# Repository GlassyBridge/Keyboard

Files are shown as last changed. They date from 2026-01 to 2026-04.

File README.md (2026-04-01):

<h1 align="center"> MK-1000 </h1>
<h4 align="center">A Modular-Wireless Keyboard </h4>
<div align="center">
  
</div>
<p align="center">A fully custom modular keyboard that has both wireless and wired capabilities, uses MX hotswap switches (with per key RGB lighting) and magnetic pogo pin connectors with I2C protocol.</p>
<h2></h2>
<h2> Features </h2>

- Works over USB-C (wired) or Bluetooth (wireless)
- Integrated magnetic pogo pins for stable I2C connection and adding external modules (numberpads, macropads or OLED modules)
- Integrated charging circuit for portability and wireless operation
- Uses MX hotswap sockets for key switch connections
- Features SK6812MINI-E back mounted LEDs for customizable per key RGB lighting
- Includes a dedicated SWD interface for debugging and development
- A dedicated slide switch to manage battery life

<h2> Why this project? </h2>

This project was made as an attempt to tackle more complex hardware from my previous projects. I spent a lot of time designing and reiterating it and its purpose is simple. I made it to function as a plug and play device that has modular capabilities.

I also wanted a cool looking keyboard so I added features I liked into this one big project.

<h2>Design</h2>
<h3>Schematic</h3>
Main_Board_Schematic
Keypad_Module_Schematic
<h4 align="center">Main board & Keypad</h4>
<h3>PCB</h3>
Back PCB
<h4 align="center">PCB back</h4>
Front PCB
<h4 align="center">PCB front</h4>
PCB
<h4 align="center">PCB</h4>
No-Components 3D View front
No-Components 3D View back
<h4 align="center">PCB 3D model</h4>
3D view front
3D view back
<h4 align="center">PCB 3D model with components</h4>
How to connect the batteries
<h4 align="center">Wiring Diagram</h4>

<h2>Firmware</h2>

Available in the `Firmware` folder. (Basic version for now. I'll update it once I built the keyboard)
<h2>Bill of Materials</h2>

| Name | Reference | Qty | moq | Price ($) | Shipping | Link |
| --- | --- | :---: | --- | --- | --- | :---: |
| OLED Screens (128X32) | Brd11 | 1 | 1 | 2.42 | Aliexpress | [Aliexpress](https://www.aliexpress.us/item/3256806165075447.html) |
| ------------ (128X64) | Brd12 | 1 | 1 | 4.18 | Aliexpress | [Aliexpress](https://www.aliexpress.us/item/3256810159598938.html) |
| 1X6 Magnetic Pogo Pins | Conn1-Conn8 | 8(4 pairs) | 5p  | 25.25 | Aliexpress | [Aliexpress](https://www.aliexpress.us/item/3256805098127227.html) |
| Capacitors (10uF) | C1-C4 | 4 | 20  | 0.43 | LCSC | [C15850](https://www.lcsc.com/product-detail/C15850.html) |
| ---------- (4.7uF) | C5,C6 | 2 | 20  | 0.29 | LCSC | [C1779](https://www.lcsc.com/product-detail/C1779.html) |
| ---------- (22uF) | C7,C8 | 2 | 20  | 1.12 | LCSC | [C12891](https://www.lcsc.com/product-detail/C12891.html) |
| Diodes | D1-D99 | 99 | 100 | 0.93 | LCSC | [C2099](https://www.lcsc.com/product-detail/C2099.html) |
| ---------- (SS34) | SS34 | 1 | 20  | 0.56 | LCSC | [C908680](https://www.lcsc.com/product-detail/C908680.html) |
| ESDA5V3L | ESD1,ESD2 | 2 | 10  | 0.39 | LCSC | [C587142](https://www.lcsc.com/product-detail/C587142.html) |
| USB Connector | J1 | 1 | 5 | 0.84 | LCSC | [C165948](https://www.lcsc.com/product-detail/C165948.html) |
| 2x3 1mm PinHeader | J2 | 1 | 20  | 0.65 | LCSC | [C6837603](https://www.lcsc.com/product-detail/C6837603.html) |
| Inductors  (10uH) | L1 | 1 | 10  | 0.47 | LCSC | [C88173](https://www.lcsc.com/product-detail/C88173.html) |
| ---------- (22uH) | L2 | 1 | 5 | 0.83 | LCSC | [C27442](https://www.lcsc.com/product-detail/C27442.html) |
| SK6812MINI-E (LEDs) | LED1-LED99  | 99 | 100 | 7.45 | LCSC | [C5149201](https://www.lcsc.com/product-detail/C5149201.html) |
| P_Mosfets | Q1-Q3 | 3 | 10  | 0.65 | LCSC | [C10487](https://www.lcsc.com/product-detail/C10487.html) |
| Resistors  (110K) | R1 | 2 | 100 | 0.19 | LCSC | [C2907221](https://www.lcsc.com/product-detail/C2907221.html) |
| ---------- (5K1) | R2,R4 | 2 | 100 | 0.24 | LCSC | [C27834](https://www.lcsc.com/product-detail/C27834.html) |
| ---------- (100K) | R3,R5,R6 | 2 | 100 | 0.22 | LCSC | [C2933502](https://www.lcsc.com/product-detail/C2933502.html) |
| ---------- (4K7) | R7,R12,R18  | 4 | 100 | 0.19 | LCSC | [C17673](https://www.lcsc.com/product-detail/C17673.html) |
| ---------- (27R) | R8,R11 | 2 | 100 | 0.22 | LCSC | [C17594](https://www.lcsc.com/product-detail/C17594.html) |
| ---------- (806K) | R9,R16,R21  | 3 | 100 | 0.22 | LCSC | [C2933502](https://www.lcsc.com/product-detail/C2933502.html) |
| ---------- (2M) | R10,R17,R22 | 3 | 100 | 0.30 | LCSC | [C26112](https://www.lcsc.com/product-detail/C26112.html) |
| ---------- (15K) | R13 | 1 | 100 | 0.21 | LCSC | [C2930170](https://www.lcsc.com/product-detail/C2930170.html) |
| ---------- (10K) | R14,R19 | 2 | 100 | 0.25 | LCSC | [C17414](https://www.lcsc.com/product-detail/C17414.html) |
| ---------- (2K) | R15 | 1 | 100 | 0.25 | LCSC | [C17604](https://www.lcsc.com/product-detail/C17604.html) |
| Rotary Encoder | RE1 | 1 | 1 | 1.87 | LCSC | [C470742](https://www.lcsc.com/product-detail/C470742.html) |
| Slide switch (1825232-1) | SPDT1 | 1 | 1 | 0.93 | LCSC | [C5167252](https://www.lcsc.com/product-detail/C5167252.html) |
| MT3608 | U1 | 1 | 10  | 0.79 | LCSC | [C84817](https://www.lcsc.com/product-detail/C84817.html) |
| USB6B1 | U2 | 1 | 1 | 0.47 | LCSC | [C283483](https://www.lcsc.com/product-detail/C283483.html) |
| MDBT50Q-1MV2 (MCU) | U3 | 1 | 1 | 10.10 | SEED | [Seed Studio](https://www.seeedstudio.com/MDBT50Q-1M-nRF52840-Based-BLE-Module-p-3147.html) |
| MCP73831T-2ACI/OT | U4 | 1 | 1 | 0.74 | LCSC | [C424093](https://www.lcsc.com/product-detail/C424093.html) |
| XIAO-nRF52840-SMD (MCU)  | U5 | 1 | 1 | 9.90 | 3.75 | [Seed Studio](https://www.seeedstudio.com/Seeed-XIAO-BLE-nRF52840-p-5201.html) |
| MCP23017 | U6 | 1 | 1 | 2.03 | LCSC | [C639770](https://www.lcsc.com/product-detail/C639770.html) |
| 74LV1T08GV | U7,U8 | 2 | 1 | 2.12 | LCSC | [C547934](https://www.lcsc.com/product-detail/C547934.html) |
| Keys ----- (Sockets) | SW1-SW99 | 99 | 110 | 8.18 | Aliexpress | [Aliexpress](https://www.aliexpress.us/item/3256809001207500.html) |
| ---------- (Switches) | - | 99 | 105 | 21.85 (T) | Aliexpress | [Aliexpress](https://www.aliexpress.us/item/3256807647145642.html) |
| ---------- (Key Caps) | - | 99 | - | 7.48 (T)  | Aliexpress | [Aliexpress](https://www.aliexpress.us/item/3256808975886837.html) |
| ---------- (Stabilizers) | - | 5 | - | 5.78 (T)  | Aliexpress | [Aliexpress](https://www.aliexpress.us/item/3256801499984864.html) |
| lithium batteries | - | 2 | - | 18.16 (T) | Aliexpress | [Aliexpress](https://www.aliexpress.us/item/3256811743915654.html) |

> *T for total price

| Supplier | cost  | Shipping | Total cost |
| --- | ----- | --- | --- |
| LCSC | 24.65 | 13.08 | 37.73 |
| Aliexpress | 93.30 | 2.69 | 96.44 |
| SEED | 20 | 8.55 | 28.55 |
| JLCPCB | 29.90 | 20.14 | 50.04 |
| Total | - | - | 212.76 |

<h2>Keyboard Case</h2>

A very basic case is provided in the `CAD` folder.



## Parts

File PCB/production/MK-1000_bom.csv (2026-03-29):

Designator | Footprint | Quantity | Value | LCSC Part #
BRD1 | OLED-TH_L38.0-W12.0_HS91L02W2C01 | 1 | SH1106
BRD2 | 128x64OLED | 1 | SH1106
C1, C2, C3, C4 | 0805 | 4 | 10uF | C15850
C5, C6 | 0805 | 2 | 4.7uF | C1779
C7, C8 | 1206 | 2 | 22uF
CONN1, CONN3, CONN5, CONN7 | Pogopin_Conn_1x4_Female | 4 | Conn_01x04_Pin
CONN2, CONN4, CONN6, CONN8 | Pogopin_Conn_1x4_Male | 4 | Conn_01x04_Pin
D1, D10, D11, D12, D13, D14, D15, D16, D17, D18, D19, D2, D20, D21, D22, D23, D24, D25, D26, D27, D28, D29, D3, D30, D31, D32, D33, D34, D35, D36, D37, D38, D39, D4, D40, D41, D42, D43, D44, D45, D46, D47, D48, D49, D5, D50, D51, D52, D53, D54, D55, D56, D57, D58, D59, D6, D60, D61, D62, D63, D64, D65, D66, D67, D68, D69, D7, D70, D71, D72, D73, D74, D75, D76, D77, D78, D79, D8, D80, D81, D82, D83, D84, D85, D86, D87, D88, D89, D9, D90, D91, D92, D93, D94, D95, D96, D97, D98, D99 | D_SOD-123 | 99 | D | C2099
ESD1, ESD2 | SOT-23-3 | 2 | ESDA5V3L | C587142
J1 | USB_C_Receptacle_HRO_TYPE-C-31-M-12 | 1 | USB_C_Receptacle_USB2.0_14P | C165948
J2 | PinHeader_2x03_P1.00mm_Vertical | 1 | Conn_02x03_Odd_Even | C6837603
L1 | 0805 | 1 | 10uH
L2 | IND-SMD_L7.1-W6.6 | 1 | 22uH
LED1, LED10, LED11, LED12, LED13, LED14, LED15, LED16, LED17, LED18, LED19, LED2, LED20, LED21, LED22, LED23, LED24, LED25, LED26, LED27, LED28, LED29, LED3, LED30, LED31, LED32, LED33, LED34, LED35, LED36, LED37, LED38, LED39, LED4, LED40, LED41, LED42, LED43, LED44, LED45, LED46, LED47, LED48, LED49, LED5, LED50, LED51, LED52, LED53, LED54, LED55, LED56, LED57, LED58, LED59, LED6, LED60, LED61, LED62, LED63, LED64, LED65, LED66, LED67, LED68, LED69, LED7, LED70, LED71, LED72, LED73, LED74, LED75, LED76, LED77, LED78, LED79, LED8, LED80, LED81, LED82, LED83, LED84, LED85, LED86, LED87, LED88, LED89, LED9, LED90, LED91, LED92, LED93, LED94, LED95, LED96, LED97, LED98, LED99 | LED | 99 | SK6803MINI-E
Q1, Q2, Q3 | SOT-23 | 3 | Q_PMOS_GSD | C10487
R1 | 0805 | 1 | 110k
R10, R17, R22 | 0805 | 3 | 2M | C26112
R11, R8 | 0805 | 2 | 27R | C17594
R12, R18, R20, R7 | 0805 | 4 | 4K7 | C17673
R13 | 0805 | 1 | 15k
R14, R19 | 0805 | 2 | 10K | C17414
R15 | 0805 | 1 | 2K | C17604
R16, R21, R9 | 0805 | 3 | 806K | C2933502
R2, R4 | 0805 | 2 | 5K1 | C27834
R3, R5, R6 | 0805 | 3 | 100K | C2933502
RE1 | RotaryEncoder_Alps_EC11E-Switch_Vertical_H20mm_CircularMountingHoles | 1 | RotaryEncoder_Switch
SPDT1 | 1825232-1 | 1 | SW_SPDT
SS34 | SS34 | 1 | D
SW1, SW10, SW11, SW12, SW13, SW14, SW15, SW16, SW17, SW18, SW19, SW2, SW20, SW21, SW22, SW23, SW24, SW25, SW26, SW27, SW29, SW3, SW31, SW32, SW33, SW34, SW35, SW36, SW37, SW38, SW39, SW4, SW40, SW41, SW42, SW44, SW46, SW47, SW48, SW49, SW5, SW50, SW51, SW52, SW53, SW54, SW55, SW56, SW58, SW6, SW60, SW61, SW62, SW63, SW64, SW65, SW66, SW67, SW68, SW69, SW7, SW71, SW72, SW73, SW74, SW75, SW77, SW78, SW79, SW8, SW80, SW81, SW82, SW83, SW84, SW85, SW86, SW87, SW88, SW89, SW9, SW91, SW92, SW93, SW94, SW95, SW96, SW99 | MX_HS_1u | 88 | SW_Push | C5333465
SW28, SW98 | MX_HS_2u | 2 | SW_Push | C5333465
SW30, SW43 | MX_HS_1.5u | 2 | SW_Push | C5333465
SW45, SW70 | MX_HS_1.75u | 2 | SW_Push | C5333465
SW57, SW59 | MX_HS_2.25u | 2 | SW_Push | C5333465
SW76 | MX_HS_6u | 1 | SW_Push | C5333465
SW90, SW97 | MX_HS_2u_90deg | 2 | SW_Push | C5333465
U1 | SOT-23-6 | 1 | MT3608
U2 | SOIC-8_3.9x4.9mm_P1.27mm | 1 | USB6B1 | C283483
U3 | Raytac_MDBT50Q | 1 | MDBT50Q-1MV2 | C5118826
U4 | SOT-23-5 | 1 | MCP73831-2-OT | C424093
U5 | modified-XIAO-nRF52840-SMD | 1 | XIAO-nRF52840-SMD | C37327670
U6 | QFN-28-1EP_6x6mm_P0.65mm_EP4.25x4.25mm | 1 | MCP23017_ML | C639770
U7, U8 | SC-74A-5_1.55x2.9mm_P0.95mm | 2 | 74LV1T08GV

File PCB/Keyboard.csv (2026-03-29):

Name | Reference | Qty | Value | Footprint | LCSC Part # | Unit Price ($) | moq | Shipping | Link
OLED Screen | Brd1,Brd2 | 2 | SH1106 | Footprints:128x64OLED,Footprints:OLED-TH_L38.0-W12.0_HS91L02W2C01 |  | 1.89 |  | $0.99 | https://www.aliexpress.com/item/1005009242613187.html
Capacitors | C1,C2,C3,C4 | 4 | 10uF | Capacitor_SMD:C_0805_2012Metric | C15850 | 0.01 |  |  | https://jlcpcb.com/partdetail/C15850
 | C5,C6 | 2 | 4.7uF | Capacitor_SMD:C_0805_2012Metric | C1779 | 0.01 |  |  | https://jlcpcb.com/partdetail/C1779
 | C7,C8 | 2 | 22uF | Capacitor_SMD:C_1206_3216Metric
Connectors | Conn1,Conn2,Conn3,Conn4,Conn5,Conn6,Conn7,Conn8 | 8 | Conn_01x04_Pin | Footprints:Pogopin_Conn_1x4_Female,Footprints:Pogopin_Conn_1x4_Male
Diodes | D1,D2,D3,D4,D5,D6,D7,D8,D9,D10,D11,D12,D13,D14,D15,D16,D17,D18,D19,D20,D21,D22,D23,D24,D25,D26,D27,D28,D29,D30,D31,D32,D33,D34,D35,D36,D37,D38,D39,D40,D41,D42,D43,D44,D45,D46,D47,D48,D49,D50,D51,D52,D53,D54,D55,D56,D57,D58,D59,D60,D61,D62,D63,D64,D65,D66,D67,D68,D69,D70,D71,D72,D73,D74,D75,D76,D77,D78,D79,D80,D81,D82,D83,D84,D85,D86,D87,D88,D89,D90,D91,D92,D93,D94,D95,D96,D97,D98,D99 | 99 | D | Diode_SMD:D_SOD-123 | C2099 | 0.01 |  |  | https://jlcpcb.com/partdetail/C2099
ESDA5V3L (ESD protector for I2C lines) | ESD1,ESD2 | 2 | ESDA5V3L | Package_TO_SOT_SMD:SOT-23-3 | C587142 | 0.04 |  |  | https://jlcpcb.com/partdetail/C587142
USB Connector | J1 | 1 | USB_C_Receptacle_USB2.0_14P | Connector_USB:USB_C_Receptacle_HRO_TYPE-C-31-M-12 | C165948 | 0.18 |  |  | https://jlcpcb.com/partdetail/C165948
2x3 1mm PinHeader (SWD Interface) | J2 | 1 | Conn_02x03_Odd_Even | Connector_PinHeader_1.00mm:PinHeader_2x03_P1.00mm_Vertical | C6837603 | 0.03 |  |  | https://jlcpcb.com/partdetail/C6837603
Inductors | L1 | 1 | 10uH | Inductor_SMD:L_0805_2012Metric
 | L2 | 1 | 22uH | Footprints:IND-SMD_L7.1-W6.6
LEDs | LED1,LED2,LED3,LED4,LED5,LED6,LED7,LED8,LED9,LED10,LED11,LED12,LED13,LED14,LED15,LED16,LED17,LED18,LED19,LED20,LED21,LED22,LED23,LED24,LED25,LED26,LED27,LED28,LED29,LED30,LED31,LED32,LED33,LED34,LED35,LED36,LED37,LED38,LED39,LED40,LED41,LED42,LED43,LED44,LED45,LED46,LED47,LED48,LED49,LED50,LED51,LED52,LED53,LED54,LED55,LED56,LED57,LED58,LED59,LED60,LED61,LED62,LED63,LED64,LED65,LED66,LED67,LED68,LED69,LED70,LED71,LED72,LED73,LED74,LED75,LED76,LED77,LED78,LED79,LED80,LED81,LED82,LED83,LED84,LED85,LED86,LED87,LED88,LED89,LED90,LED91,LED92,LED93,LED94,LED95,LED96,LED97,LED98,LED99 | 99 | SK6803MINI-E | Footprints:LED
P_Mosfets | Q1,Q2,Q3 | 3 | Q_PMOS_GSD | Package_TO_SOT_SMD:SOT-23 | C10487
 | R1 | 1 | 110k | Resistor_SMD:R_0805_2012Metric
 | R13 | 1 | 15k | Resistor_SMD:R_0805_2012Metric
 | R15 | 1 | 2K | Resistor_SMD:R_0805_2012Metric | C17604 | 0.01 |  |  | https://jlcpcb.com/partdetail/C17604
 | R10,R17,R22 | 3 | 2M | Resistor_SMD:R_0805_2012Metric | C26112 | 0.01 |  |  | https://jlcpcb.com/partdetail/C26112
 | R14,R19 | 2 | 10K | Resistor_SMD:R_0805_2012Metric | C17414 | 0.01 |  |  | https://jlcpcb.com/partdetail/C17414
Resistors | R2,R4 | 2 | 5K1 | Resistor_SMD:R_0805_2012Metric | C27834 | 0.01 |  |  | https://jlcpcb.com/partdetail/C27834
 | R3,R5,R6 | 3 | 100K | Resistor_SMD:R_0805_2012Metric | C2933502 | 0.01 |  |  | https://jlcpcb.com/partdetail/C2933502
 | R7,R12,R18,R20 | 4 | 4K7 | Resistor_SMD:R_0805_2012Metric | C17673 | 0.01 |  |  | https://jlcpcb.com/partdetail/C17673
 | R8,R11 | 2 | 27R | Resistor_SMD:R_0805_2012Metric | C17594 | 0.01 |  |  | https://jlcpcb.com/partdetail/C17594
 | R9,R16,R21 | 3 | 806K | Resistor_SMD:R_0805_2012Metric | C2933502 | 0.01 |  |  | https://jlcpcb.com/partdetail/C2933502
Rotary Encoder | RE1 | 1 | RotaryEncoder_Switch | Rotary_Encoder:RotaryEncoder_Alps_EC11E-Switch_Vertical_H20mm_CircularMountingHoles
Slide Switch | SPDT1 | 1 | SW_SPDT | Footprints:1825232-1
Diode | SS34 | 1 | D | Footprints:SS34
Keys | SW1,SW2,SW3,SW4,SW5,SW6,SW7,SW8,SW9,SW10,SW11,SW12,SW13,SW14,SW15,SW16,SW17,SW18,SW19,SW20,SW21,SW22,SW23,SW24,SW25,SW26,SW27,SW28,SW29,SW30,SW31,SW32,SW33,SW34,SW35,SW36,SW37,SW38,SW39,SW40,SW41,SW42,SW43,SW44,SW45,SW46,SW47,SW48,SW49,SW50,SW51,SW52,SW53,SW54,SW55,SW56,SW57,SW58,SW59,SW60,SW61,SW62,SW63,SW64,SW65,SW66,SW67,SW68,SW69,SW70,SW71,SW72,SW73,SW74,SW75,SW76,SW77,SW78,SW79,SW80,SW81,SW82,SW83,SW84,SW85,SW86,SW87,SW88,SW89,SW90,SW91,SW92,SW93,SW94,SW95,SW96,SW97,SW98,SW99 | 99 | SW_Push | Footprints:MX_HS_1.5u,Footprints:MX_HS_1.75u,Footprints:MX_HS_1u,Footprints:MX_HS_2.25u,Footprints:MX_HS_2u,Footprints:MX_HS_2u_90deg,Footprints:MX_HS_6u | C5333465 | 0.1213 | 73 |  | https://jlcpcb.com/partdetail/C5333465
MT3608 | U1 | 1 | MT3608 | Package_TO_SOT_SMD:SOT-23-6
USB6B1 (ESD protector for USB data lines) | U2 | 1 | USB6B1 | Package_SO:SOIC-8_3.9x4.9mm_P1.27mm | C283483 | 0.4702 | 19 |  | https://jlcpcb.com/partdetail/C283483
MDBT50Q-1MV2 (MCU) | U3 | 1 | MDBT50Q-1MV2 | RF_Module:Raytac_MDBT50Q | C5118826 | 6.9468 | 2 |  | https://jlcpcb.com/partdetail/C5118826
MCP73831T-2ACI/OT | U4 | 1 | MCP73831-2-OT | Package_TO_SOT_SMD:SOT-23-5 | C424093 | 0.72 |  |  | https://jlcpcb.com/partdetail/C424093
XIAO-nRF52840-SMD (MCU) | U5 | 1 | XIAO-nRF52840-SMD | Footprints:modified-XIAO-nRF52840-SMD | C37327670 | 0.0196 | 447 |  | https://jlcpcb.com/partdetail/C37327670
MCP23017 (GPIO expander) | U6 | 1 | MCP23017_ML | Package_DFN_QFN:QFN-28-1EP_6x6mm_P0.65mm_EP4.25x4.25mm | C639770 | 1.93 |  |  | https://jlcpcb.com/partdetail/C639770
74LV1T08GV | U7,U8 | 2 | 74LV1T08GV | Package_TO_SOT_SMD:SC-74A-5_1.55x2.9mm_P0.95mm

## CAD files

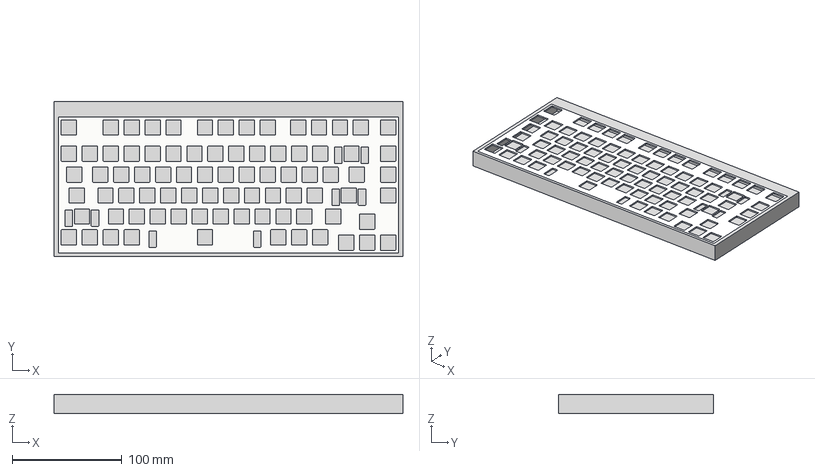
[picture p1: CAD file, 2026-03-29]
CAD/Keyboard_case.step
317.6 x 140.8 x 17.5 mm

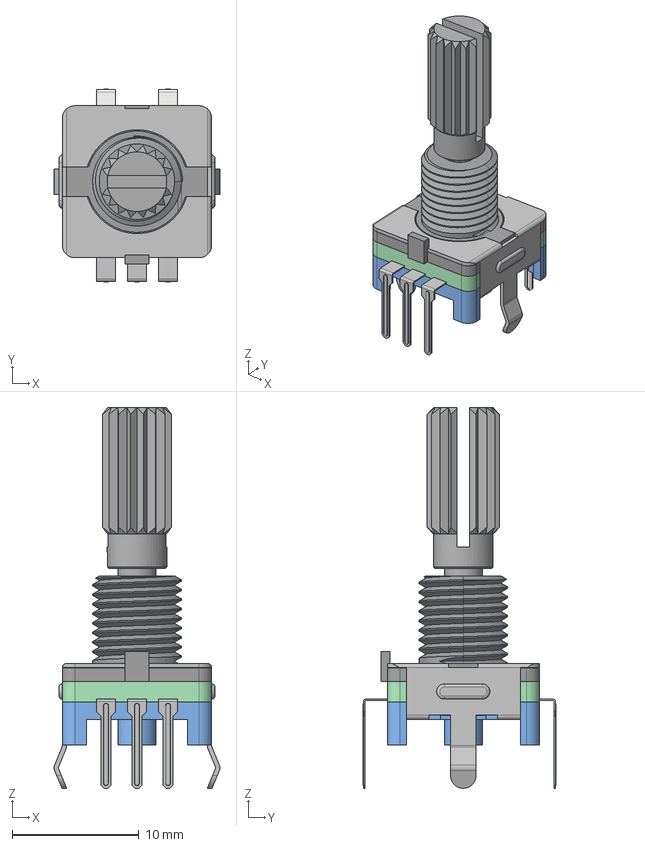
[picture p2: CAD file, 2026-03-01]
PCB/3d models/EC11_Rotary_Encoder_Switched.step
13.1 x 15.3 x 30.1 mm

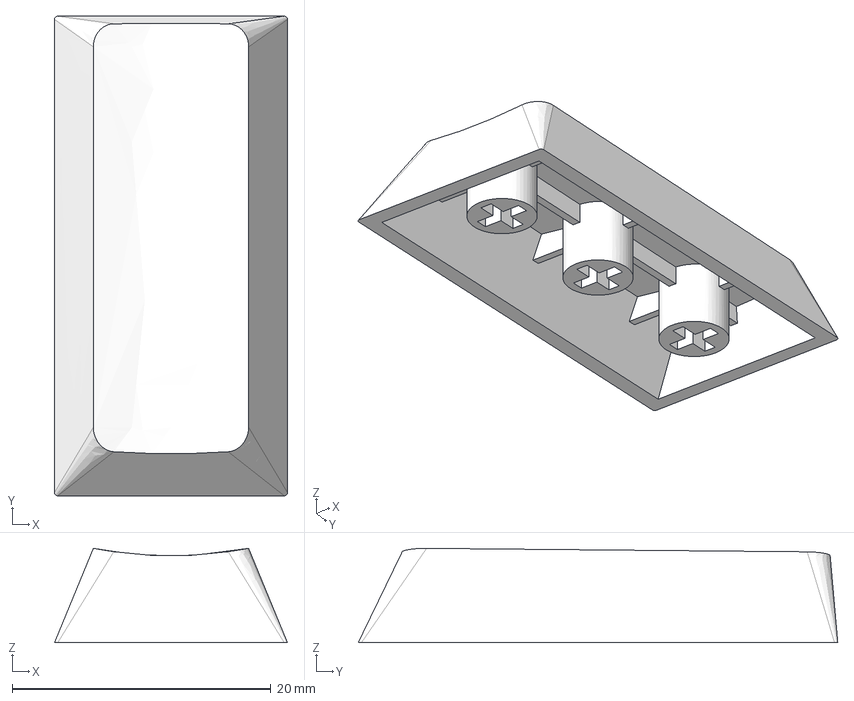
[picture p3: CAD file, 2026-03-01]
PCB/3d models/Keycaps/KeyCap_U2_V.step
18.0 x 37.0 x 7.28 mm

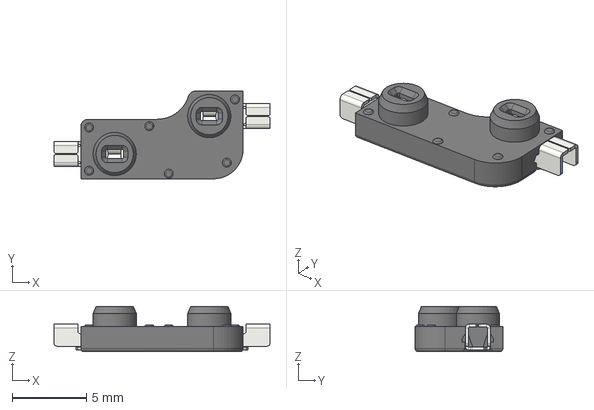
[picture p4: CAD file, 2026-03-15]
PCB/3d models/Keyswitches/HS_CPG151101S11_MX.step
14.5 x 5.89 x 3.05 mm
Contact x 2

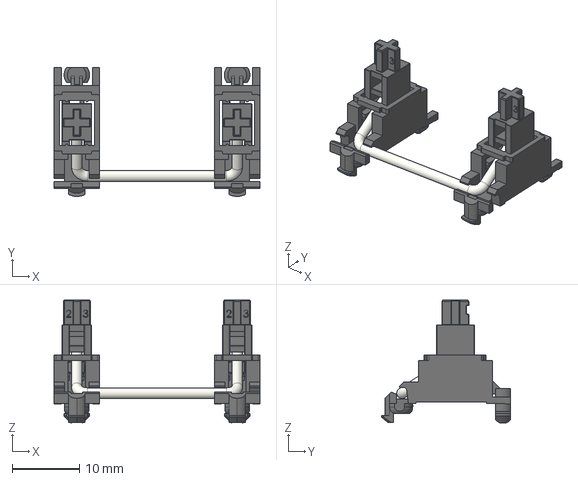
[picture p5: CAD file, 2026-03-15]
PCB/3d models/Keyswitches/Stabilizers/Stabilizer_Cherry_MX_2.00u.stp
30.7 x 19.2 x 18.3 mm

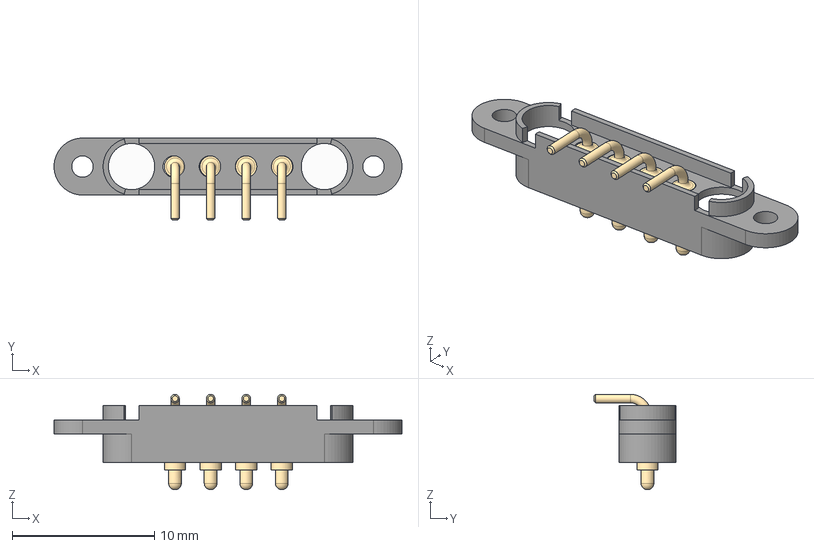
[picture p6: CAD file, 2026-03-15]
PCB/3d models/PogoPins/Pogo_Male_V2.step
24.4 x 5.75 x 6.70 mm
Magnetic Pogo Connector 4 Pin (Type 4)005
Magnetic Pogo Connector 4 Pin (Type 4)004
Case001
Magnet003
Magnet004
Magnetic Pogo Connector 4 Pin (Type 4)003
Magnetic Pogo Connector 4 Pin (Type 4)006

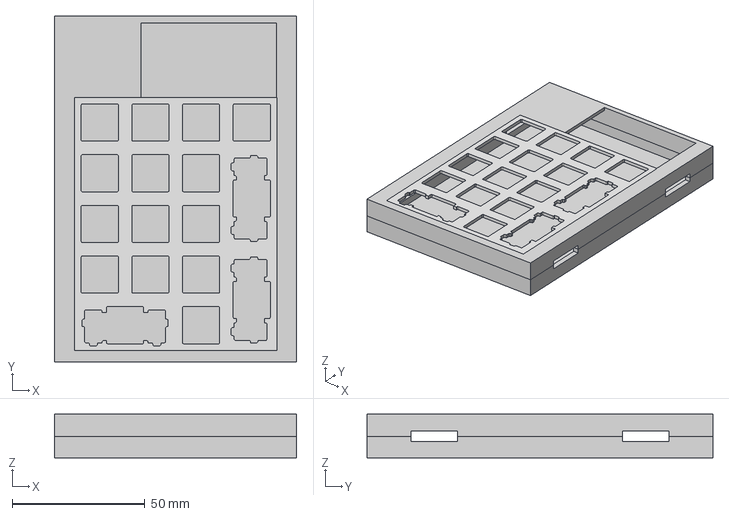
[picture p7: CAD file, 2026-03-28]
CAD/Keypad_case.step
91.0 x 130.0 x 16.5 mm

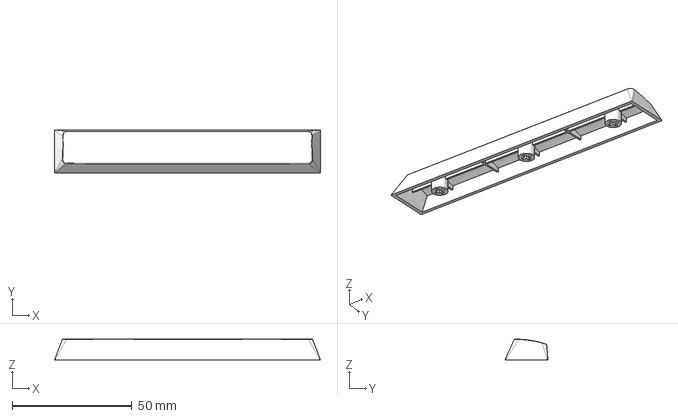
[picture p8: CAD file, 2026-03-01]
PCB/3d models/Keycaps/KeyCap_U6.step
111.1 x 18.0 x 8.70 mm

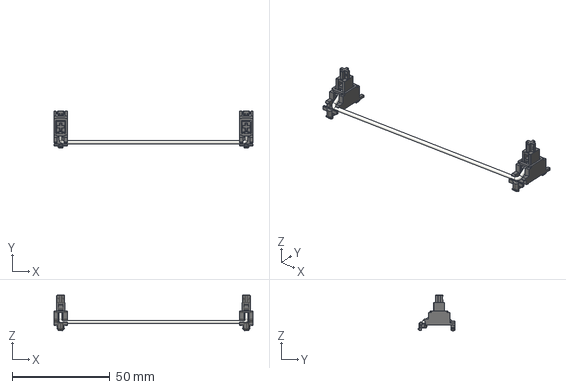
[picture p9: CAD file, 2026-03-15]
PCB/3d models/Keyswitches/Stabilizers/Stabilizer_Cherry_MX_6.00u.stp
102.1 x 19.2 x 18.3 mm

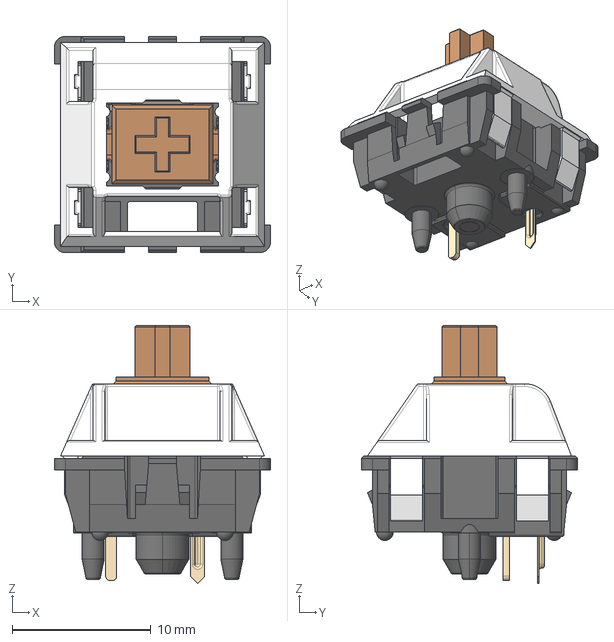
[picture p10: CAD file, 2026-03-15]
PCB/3d models/Keyswitches/SW_Cherry_MX_PCB.stp
15.6 x 15.6 x 18.6 mm

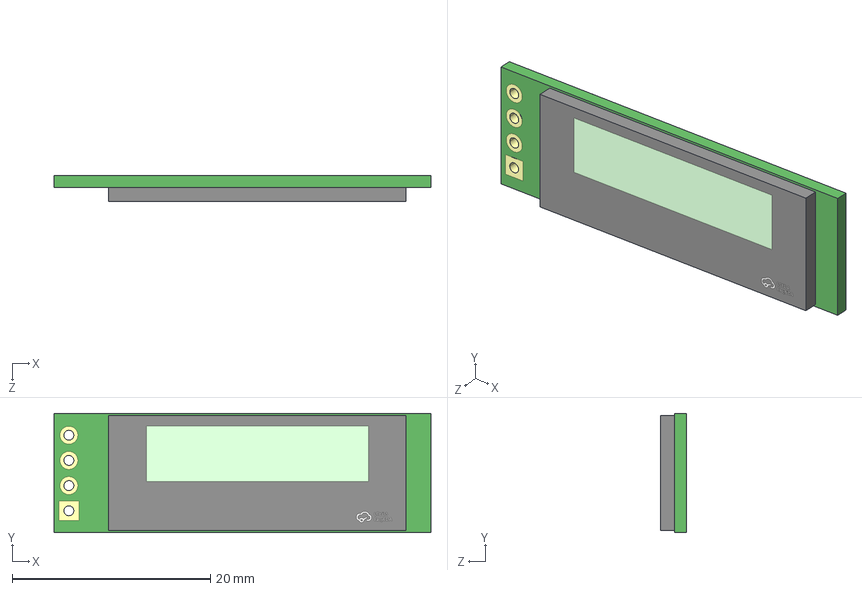
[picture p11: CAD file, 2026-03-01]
PCB/3d models/OLED-TH_L38.0-W12.0_HS91L02W2C01.step
38.0 x 12.0 x 2.62 mm

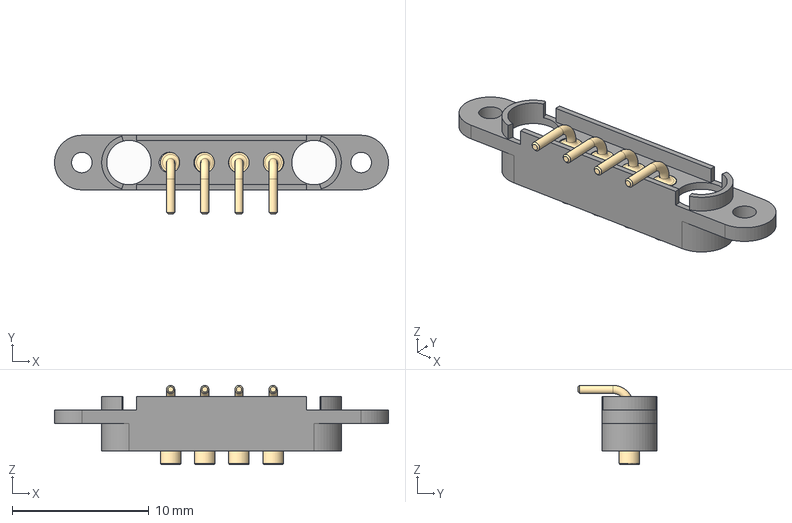
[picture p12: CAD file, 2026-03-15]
PCB/3d models/PogoPins/Pogo_Female_V2.step
24.4 x 5.75 x 5.80 mm
Magnetic Pogo Connector 4 Pin (Type 3)008
Magnetic Pogo Connector 4 Pin (Type 3)009
Magnetic Pogo Connector 4 Pin (Type 3)010
Magnetic Pogo Connector 4 Pin (Type 3)011
Case
Magnet2
Magnet1

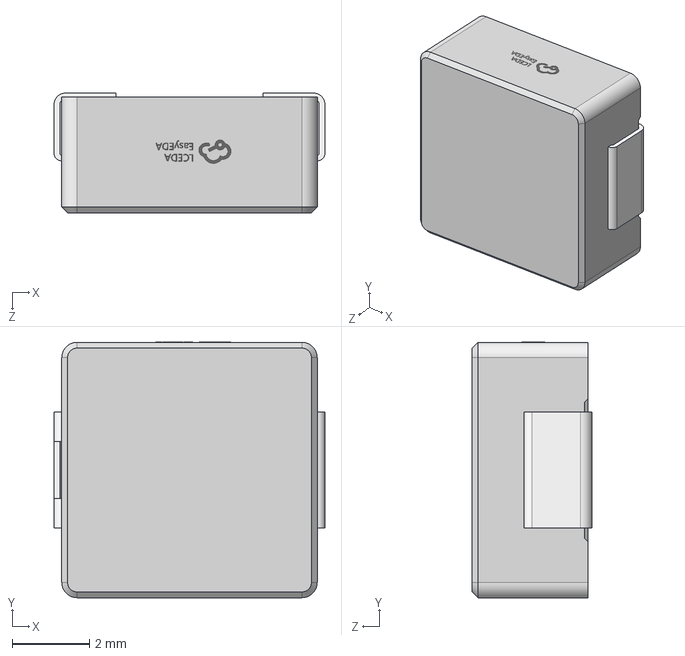
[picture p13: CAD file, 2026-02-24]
PCB/3d models/IND-SMD_L6.6-W7.1-H3.0.step
7.00 x 6.60 x 3.10 mm

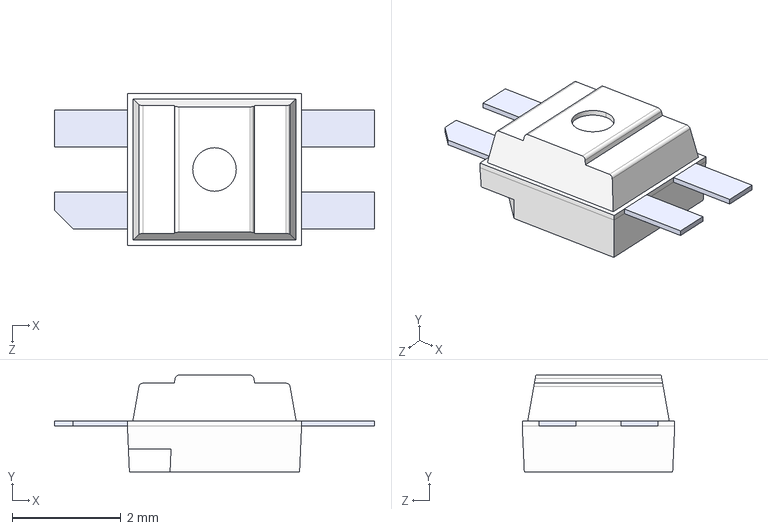
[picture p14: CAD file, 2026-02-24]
PCB/3d models/SK6812-E--3DModel-STEP-418109.STEP
5.88 x 1.78 x 2.80 mm

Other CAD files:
PCB/3d models/SS34.step
PCB/3d models/TYPE-C-31-M-12--3DModel-STEP-56544.STEP
PCB/3d models/OLED-128x64-0.96.step
PCB/3d models/XIAO-nRF52840 v15.step
CAD/Keyboard_case.f3d
CAD/Keypad_case_top.glb.f3d
PCB/3d models/1825232-1.step

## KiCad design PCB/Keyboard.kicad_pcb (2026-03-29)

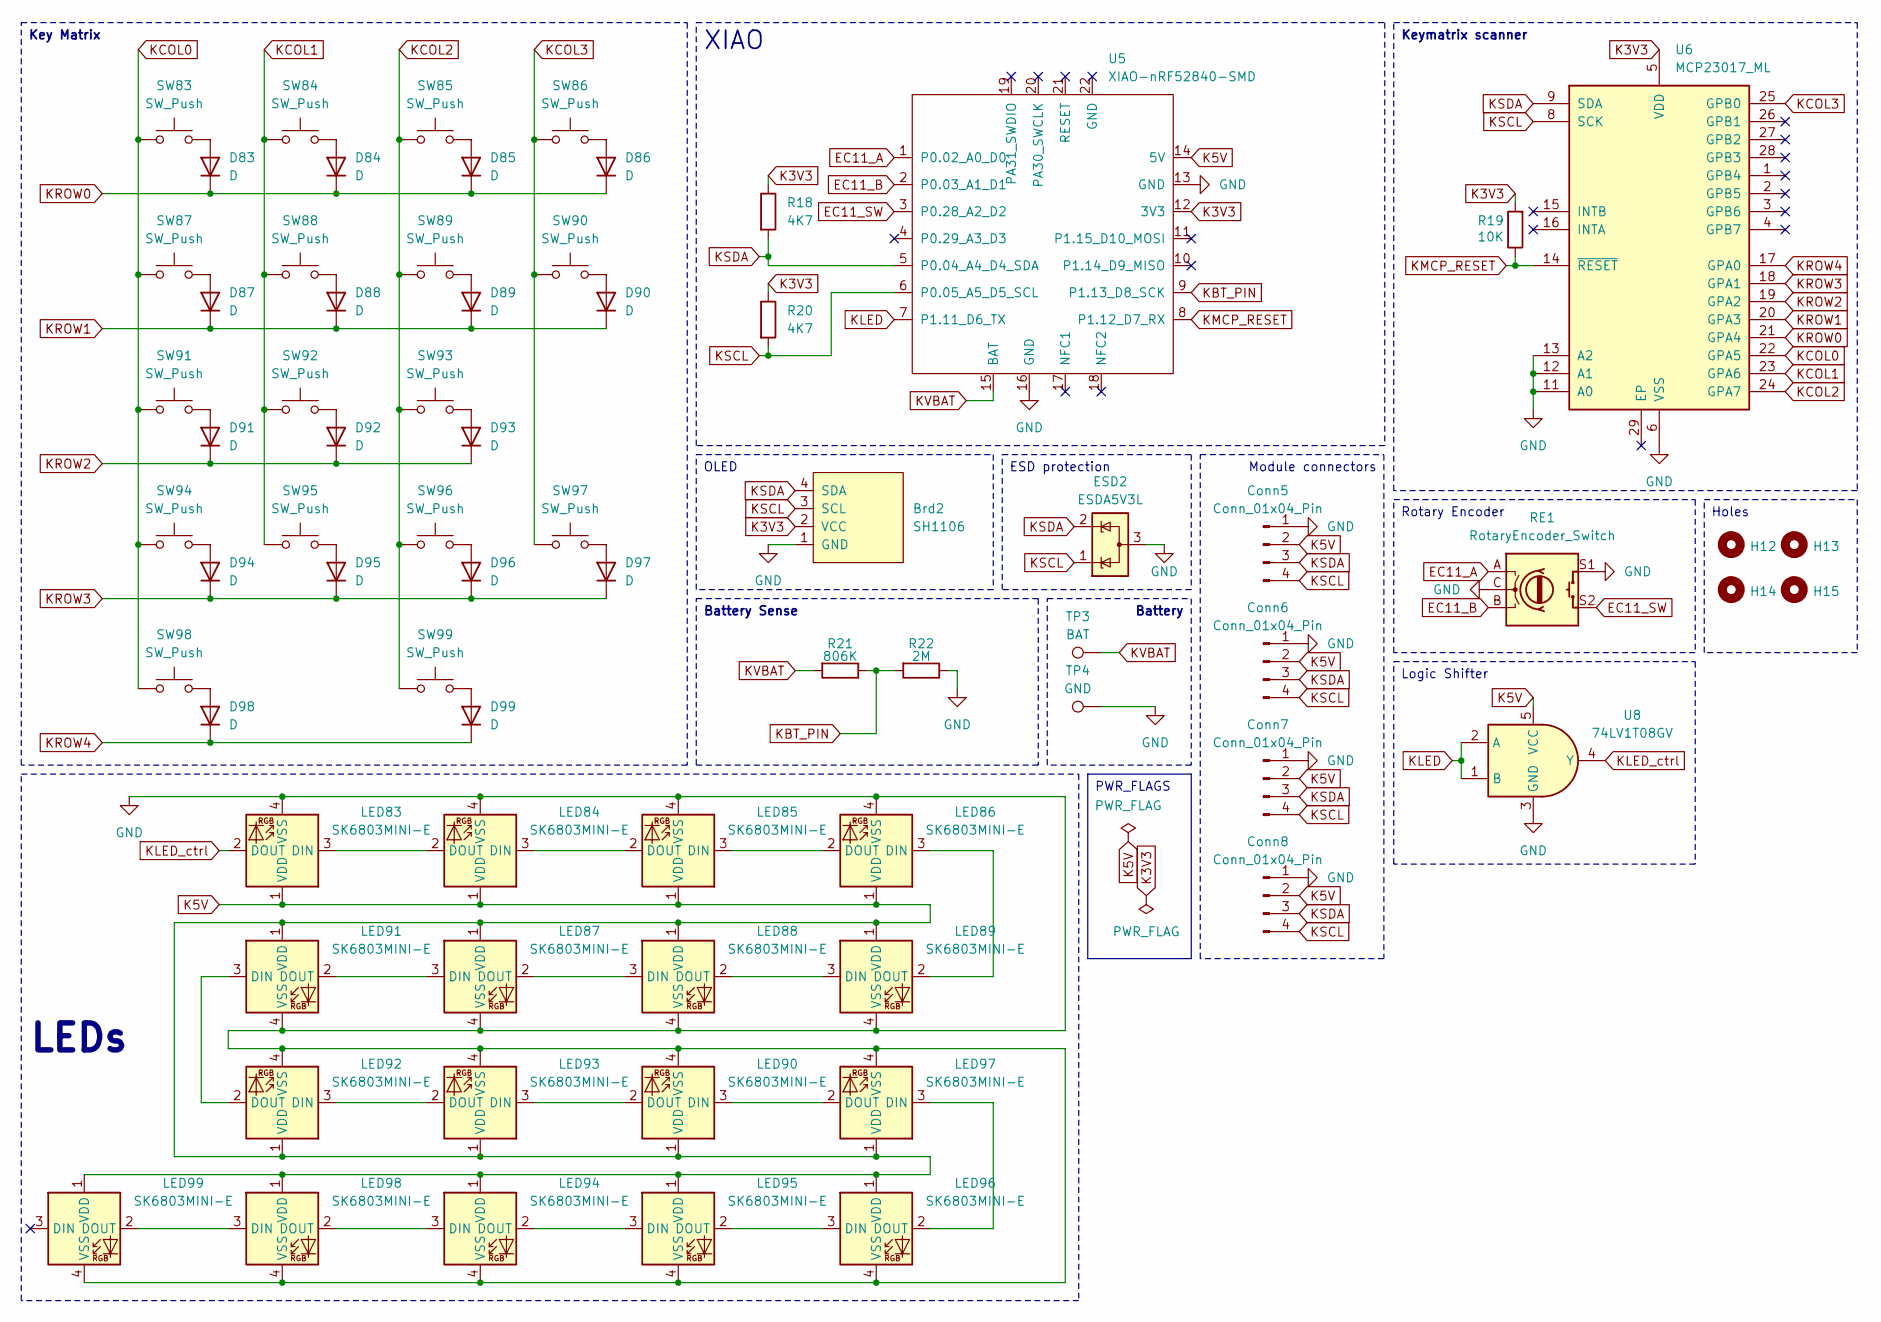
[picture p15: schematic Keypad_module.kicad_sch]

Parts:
Brd2: SH1106; 128x64OLED
Conn5, Conn7: Conn_01x04_Pin; Pogopin_Conn_1x4_Female
Conn6, Conn8: Conn_01x04_Pin; Pogopin_Conn_1x4_Male
D83, D84, D85, D86, D87, D88, D89, D90, D91, D92, D93, D94, D95, D96, D97, D98, D99: D; D_SOD-123; LCSC Part # C2099
ESD2: ESDA5V3L; SOT-23-3; LCSC Part # C587142
H12, H13, H14, H15: MountingHole; MountingHole_3.2mm_M3
LED83, LED84, LED85, LED86, LED87, LED88, LED89, LED90, LED91, LED92, LED93, LED94, LED95, LED96, LED97, LED98, LED99: SK6803MINI-E; LED
R18, R20: 4K7; R_0805_2012Metric; LCSC Part # C17673
R19: 10K; R_0805_2012Metric; LCSC Part # C17414
R21: 806K; R_0805_2012Metric; LCSC Part # C2933502
R22: 2M; R_0805_2012Metric; LCSC Part # C26112
RE1: RotaryEncoder_Switch; RotaryEncoder_Alps_EC11E-Switch_Vertical_H20mm_CircularMoun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
SW83, SW84, SW85, SW86, SW87, SW88, SW89, SW91, SW92, SW93, SW94, SW95, SW96, SW99: SW_Push; MX_HS_1u; LCSC Part # C5333465
SW90, SW97: SW_Push; MX_HS_2u_90deg; LCSC Part # C5333465
SW98: SW_Push; MX_HS_2u; LCSC Part # C5333465
TP3: BAT; TestPoint_Pad_D2.0mm
TP4: GND; TestPoint_Pad_D2.0mm
U5: XIAO-nRF52840-SMD; modified-XIAO-nRF52840-SMD; LCSC Part # C37327670
U6: MCP23017_ML; QFN-28-1EP_6x6mm_P0.65mm_EP4.25x4.25mm; LCSC Part # C639770
U8: 74LV1T08GV; SC-74A-5_1.55x2.9mm_P0.95mm

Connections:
EC11_A: RE1.A, U5.1 (P0.02_A0_D0)
EC11_B: RE1.B, U5.2 (P0.03_A1_D1)
EC11_SW: RE1.S2, U5.3 (P0.28_A2_D2)
GND: Brd2.1 (GND), Conn5.1, Conn6.1, Conn7.1, Conn8.1, ESD2.3 (A), LED83.4 (VSS), LED84.4 (VSS), LED85.4 (VSS), LED86.4 (VSS), LED87.4 (VSS), LED88.4 (VSS), LED89.4 (VSS), LED90.4 (VSS), LED91.4 (VSS), LED92.4 (VSS), LED93.4 (VSS), LED94.4 (VSS), LED95.4 (VSS), LED96.4 (VSS), LED97.4 (VSS), LED98.4 (VSS), LED99.4 (VSS), R22.1, RE1.C, RE1.S1, TP4.1, U5.13 (GND), U5.16 (GND), U6.6 (VSS), U6.11 (A0), U6.12 (A1), U6.13 (A2), U8.3 (GND); also elsewhere on the board
K3V3: Brd2.2 (VCC), R18.1, R19.2, R20.1, U5.12 (3V3), U6.5 (VDD)
K5V: Conn5.2, Conn6.2, Conn7.2, Conn8.2, LED83.1 (VDD), LED84.1 (VDD), LED85.1 (VDD), LED86.1 (VDD), LED87.1 (VDD), LED88.1 (VDD), LED89.1 (VDD), LED90.1 (VDD), LED91.1 (VDD), LED92.1 (VDD), LED93.1 (VDD), LED94.1 (VDD), LED95.1 (VDD), LED96.1 (VDD), LED97.1 (VDD), LED98.1 (VDD), LED99.1 (VDD), U5.14 (5V), U8.5 (VCC)
KBT_PIN: R21.1, R22.2, U5.9 (P1.13_D8_SCK)
KCOL0: SW83.1, SW87.1, SW91.1, SW94.1, SW98.1, U6.22 (GPA5)
KCOL1: SW84.1, SW88.1, SW92.1, SW95.1, U6.23 (GPA6)
KCOL2: SW85.1, SW89.1, SW93.1, SW96.1, SW99.1, U6.24 (GPA7)
KCOL3: SW86.1, SW90.1, SW97.1, U6.25 (GPB0)
KLED: U5.7 (P1.11_D6_TX), U8.1 (B), U8.2 (A)
KLED_ctrl: LED83.2 (DOUT), U8.4 (Y)
KMCP_RESET: R19.1, U5.8 (P1.12_D7_RX), U6.14 (~RESET)
KROW0: D83.1 (K), D84.1 (K), D85.1 (K), D86.1 (K), U6.21 (GPA4)
KROW1: D87.1 (K), D88.1 (K), D89.1 (K), D90.1 (K), U6.20 (GPA3)
KROW2: D91.1 (K), D92.1 (K), D93.1 (K), U6.19 (GPA2)
KROW3: D94.1 (K), D95.1 (K), D96.1 (K), D97.1 (K), U6.18 (GPA1)
KROW4: D98.1 (K), D99.1 (K), U6.17 (GPA0)
KSCL: Brd2.3 (SCL), Conn5.4, Conn6.4, Conn7.4, Conn8.4, ESD2.1 (K), R20.2, U5.6 (P0.05_A5_D5_SCL), U6.8 (SCK)
KSDA: Brd2.4 (SDA), Conn5.3, Conn6.3, Conn7.3, Conn8.3, ESD2.2 (K), R18.2, U5.5 (P0.04_A4_D4_SDA), U6.9 (SDA)
KVBAT: R21.2, TP3.1, U5.15 (BAT)
unnamed: D83.2 (A), SW83.2
unnamed: D84.2 (A), SW84.2
unnamed: D85.2 (A), SW85.2
unnamed: D86.2 (A), SW86.2
unnamed: D87.2 (A), SW87.2
unnamed: D88.2 (A), SW88.2
unnamed: D89.2 (A), SW89.2
unnamed: D90.2 (A), SW90.2
unnamed: D91.2 (A), SW91.2
unnamed: D92.2 (A), SW92.2
unnamed: D93.2 (A), SW93.2
unnamed: D94.2 (A), SW94.2
unnamed: D95.2 (A), SW95.2
unnamed: D96.2 (A), SW96.2
unnamed: D97.2 (A), SW97.2
unnamed: D98.2 (A), SW98.2
unnamed: D99.2 (A), SW99.2
unnamed: LED83.3 (DIN), LED84.2 (DOUT)
unnamed: LED84.3 (DIN), LED85.2 (DOUT)
unnamed: LED85.3 (DIN), LED86.2 (DOUT)
unnamed: LED86.3 (DIN), LED89.2 (DOUT)
unnamed: LED87.3 (DIN), LED91.2 (DOUT)
unnamed: LED87.2 (DOUT), LED88.3 (DIN)
unnamed: LED88.2 (DOUT), LED89.3 (DIN)
unnamed: LED90.3 (DIN), LED97.2 (DOUT)
unnamed: LED90.2 (DOUT), LED93.3 (DIN)
unnamed: LED91.3 (DIN), LED92.2 (DOUT)
unnamed: LED92.3 (DIN), LED93.2 (DOUT)
unnamed: LED94.3 (DIN), LED98.2 (DOUT)
unnamed: LED94.2 (DOUT), LED95.3 (DIN)
unnamed: LED95.2 (DOUT), LED96.3 (DIN)
unnamed: LED96.2 (DOUT), LED97.3 (DIN)
unnamed: LED98.3 (DIN), LED99.2 (DOUT)

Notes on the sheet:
ESD protection
Keymatrix scanner
Logic Shifter
LEDs
PWR_FLAGS
Module connectors
Key Matrix
XIAO
Holes
Battery Sense
Battery
OLED
Rotary Encoder

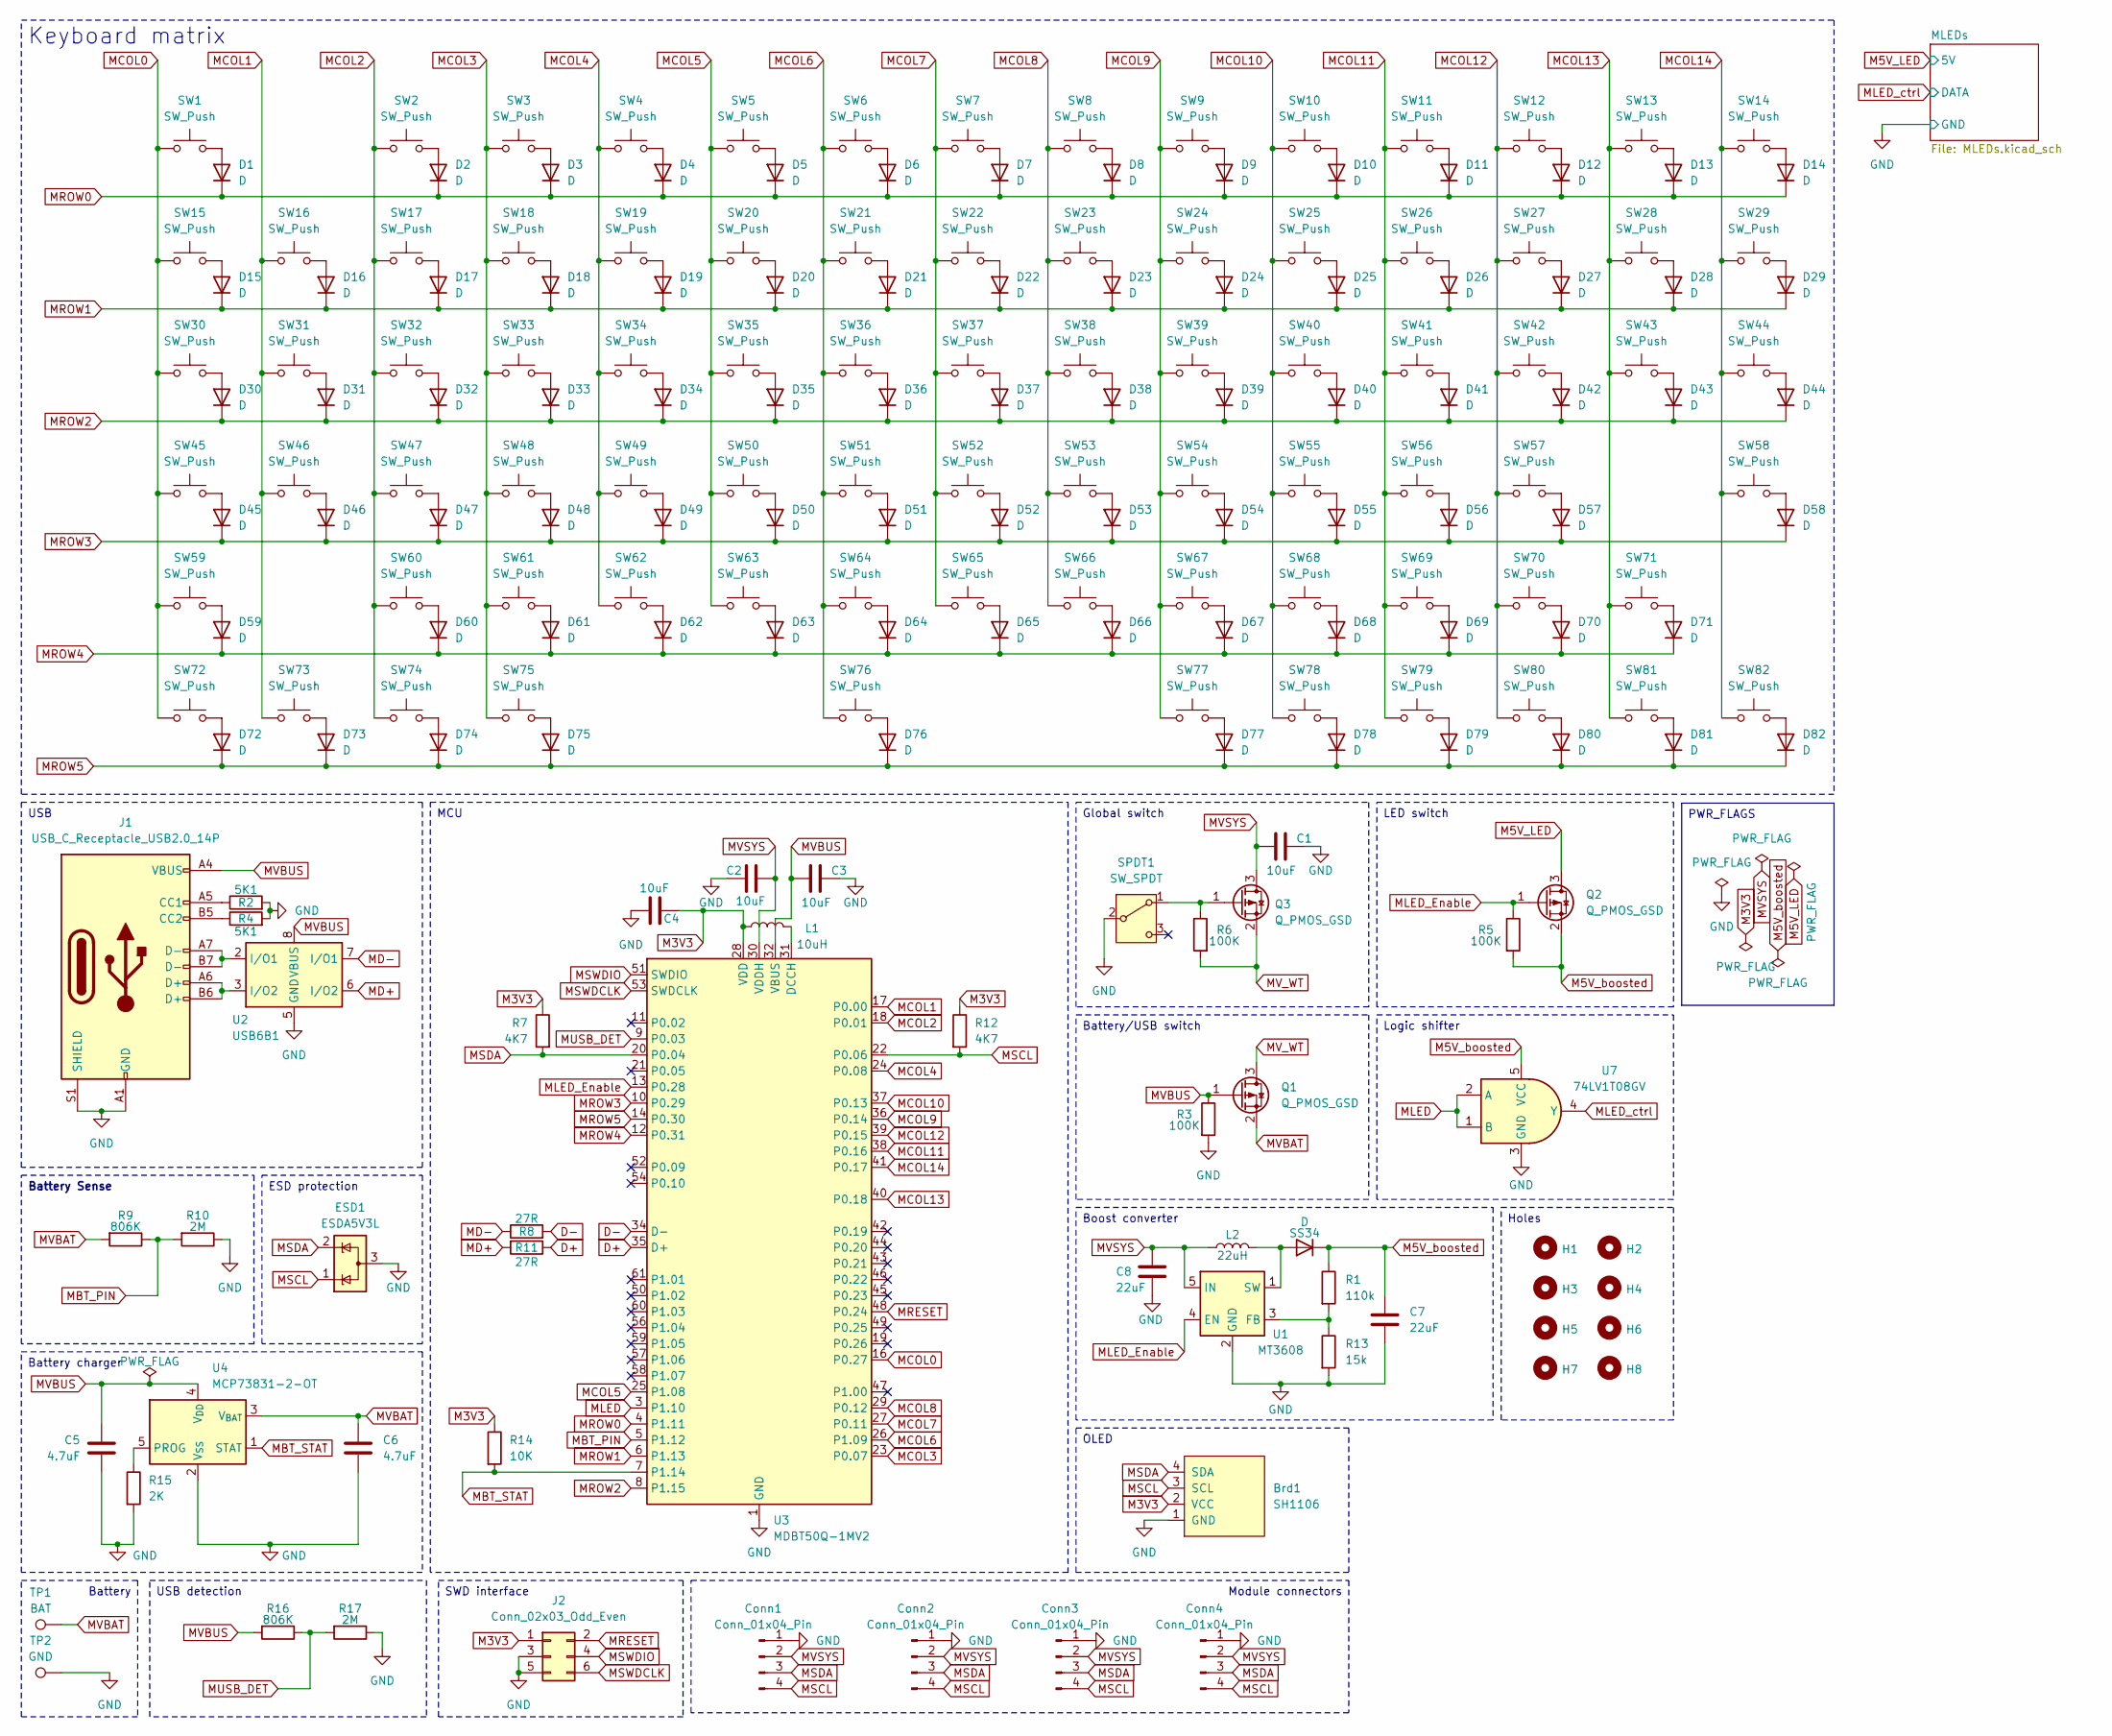
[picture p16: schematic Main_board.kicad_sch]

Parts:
Brd1: SH1106; OLED-TH_L38.0-W12.0_HS91L02W2C01
C1, C2, C3, C4: 10uF; C_0805_2012Metric; LCSC Part # C15850
C5, C6: 4.7uF; C_0805_2012Metric; LCSC Part # C1779
C7, C8: 22uF; C_1206_3216Metric
Conn1, Conn3: Conn_01x04_Pin; Pogopin_Conn_1x4_Female
Conn2, Conn4: Conn_01x04_Pin; Pogopin_Conn_1x4_Male
D1, D2, D3, D4, D5, D6, D7, D8, D9, D10, D11, D12, D13, D14, D15, D16, D17, D18, D19, D20, D21, D22, D23, D24, D25, D26, D27, D28, D29, D30, D31, D32, D33, D34, D35, D36, D37, D38, D39, D40, D41, D42, D43, D44, D45, D46, D47, D48, D49, D50, D51, D52, D53, D54, D55, D56, D57, D58, D59, D60, D61, D62, D63, D64, D65, D66, D67, D68, D69, D70, D71, D72, D73, D74, D75, D76, D77, D78, D79, D80, D81, D82: D; D_SOD-123; LCSC Part # C2099
ESD1: ESDA5V3L; SOT-23-3; LCSC Part # C587142
H1, H2, H3, H4, H5, H6, H7, H8: MountingHole; MountingHole_3.2mm_M3
J1: USB_C_Receptacle_USB2.0_14P; USB_C_Receptacle_HRO_TYPE-C-31-M-12; LCSC Part # C165948
J2: Conn_02x03_Odd_Even; PinHeader_2x03_P1.00mm_Vertical; LCSC Part # C6837603
L1: 10uH; L_0805_2012Metric
L2: 22uH; IND-SMD_L7.1-W6.6
Q1, Q2, Q3: Q_PMOS_GSD; SOT-23; LCSC Part # C10487
R1: 110k; R_0805_2012Metric
R2, R4: 5K1; R_0805_2012Metric; LCSC Part # C27834
R3, R5, R6: 100K; R_0805_2012Metric; LCSC Part # C2933502
R7, R12: 4K7; R_0805_2012Metric; LCSC Part # C17673
R8, R11: 27R; R_0805_2012Metric; LCSC Part # C17594
R9, R16: 806K; R_0805_2012Metric; LCSC Part # C2933502
R10, R17: 2M; R_0805_2012Metric; LCSC Part # C26112
R13: 15k; R_0805_2012Metric
R14: 10K; R_0805_2012Metric; LCSC Part # C17414
R15: 2K; R_0805_2012Metric; LCSC Part # C17604
SPDT1: SW_SPDT; 1825232-1
SS34: D; SS34
SW1, SW2, SW3, SW4, SW5, SW6, SW7, SW8, SW9, SW10, SW11, SW12, SW13, SW14, SW15, SW16, SW17, SW18, SW19, SW20, SW21, SW22, SW23, SW24, SW25, SW26, SW27, SW29, SW31, SW32, SW33, SW34, SW35, SW36, SW37, SW38, SW39, SW40, SW41, SW42, SW44, SW46, SW47, SW48, SW49, SW50, SW51, SW52, SW53, SW54, SW55, SW56, SW58, SW60, SW61, SW62, SW63, SW64, SW65, SW66, SW67, SW68, SW69, SW71, SW72, SW73, SW74, SW75, SW77, SW78, SW79, SW80, SW81, SW82: SW_Push; MX_HS_1u; LCSC Part # C5333465
SW28: SW_Push; MX_HS_2u; LCSC Part # C5333465
SW30, SW43: SW_Push; MX_HS_1.5u; LCSC Part # C5333465
SW45, SW70: SW_Push; MX_HS_1.75u; LCSC Part # C5333465
SW57, SW59: SW_Push; MX_HS_2.25u; LCSC Part # C5333465
SW76: SW_Push; MX_HS_6u; LCSC Part # C5333465
TP1: BAT; TestPoint_Pad_D2.0mm
TP2: GND; TestPoint_Pad_D2.0mm
U1: MT3608; SOT-23-6
U2: USB6B1; SOIC-8_3.9x4.9mm_P1.27mm; LCSC Part # C283483
U3: MDBT50Q-1MV2; Raytac_MDBT50Q; LCSC Part # C5118826
U4: MCP73831-2-OT; SOT-23-5; LCSC Part # C424093
U7: 74LV1T08GV; SC-74A-5_1.55x2.9mm_P0.95mm

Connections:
D+: R11.1, U3.35 (D+)
D-: R8.2, U3.34 (D-)
GND: Brd1.1 (GND), C1.2, C2.2, C3.2, C4.1, C5.2, C6.2, C7.2, C8.2, Conn1.1, Conn2.1, Conn3.1, Conn4.1, ESD1.3 (A), J1.A1 (GND), J1.A12 (GND), J1.B1 (GND), J1.B12 (GND), J1.S1 (SHIELD), J2.3, J2.5, R2.2, R3.2, R4.2, R10.1, R13.2, R15.2, R17.1, SPDT1.2 (B), TP2.1, U1.2 (GND), U2.4 (GND), U2.5 (GND), U3.1 (GND), U3.2 (GND), U3.15 (GND), U3.33 (GND), U3.55 (GND), U4.2 (V_{SS}), U7.3 (GND); also elsewhere on the board
M3V3: Brd1.2 (VCC), C4.2, J2.1, L1.1, R7.1, R12.1, R14.1, U3.28 (VDD)
M5V_LED: Q2.3 (D); also elsewhere on the board
M5V_boosted: C7.1, Q2.2 (S), R1.1, R5.2, SS34.1 (K), U7.5 (VCC)
MBT_PIN: R9.1, R10.2, U3.5 (P1.12)
MBT_STAT: R14.2, U3.7 (P1.14), U4.1 (STAT)
MCOL0: SW1.1, SW15.1, SW30.1, SW45.1, SW59.1, SW72.1, U3.16 (P0.27)
MCOL1: SW16.1, SW31.1, SW46.1, SW73.1, U3.17 (P0.00)
MCOL2: SW2.1, SW17.1, SW32.1, SW47.1, SW60.1, SW74.1, U3.18 (P0.01)
MCOL3: SW3.1, SW18.1, SW33.1, SW48.1, SW61.1, SW75.1, U3.23 (P0.07)
MCOL4: SW4.1, SW19.1, SW34.1, SW49.1, SW62.1, U3.24 (P0.08)
MCOL5: SW5.1, SW20.1, SW35.1, SW50.1, SW63.1, U3.25 (P1.08)
MCOL6: SW6.1, SW21.1, SW36.1, SW51.1, SW64.1, SW76.1, U3.26 (P1.09)
MCOL7: SW7.1, SW22.1, SW37.1, SW52.1, SW65.1, U3.27 (P0.11)
MCOL8: SW8.1, SW23.1, SW38.1, SW53.1, SW66.1, U3.29 (P0.12)
MCOL9: SW9.1, SW24.1, SW39.1, SW54.1, SW67.1, SW77.1, U3.36 (P0.14)
MCOL10: SW10.1, SW25.1, SW40.1, SW55.1, SW68.1, SW78.1, U3.37 (P0.13)
MCOL11: SW11.1, SW26.1, SW41.1, SW56.1, SW69.1, SW79.1, U3.38 (P0.16)
MCOL12: SW12.1, SW27.1, SW42.1, SW57.1, SW70.1, SW80.1, U3.39 (P0.15)
MCOL13: SW13.1, SW28.1, SW43.1, SW71.1, SW81.1, U3.40 (P0.18)
MCOL14: SW14.1, SW29.1, SW44.1, SW58.1, SW82.1, U3.41 (P0.17)
MD+: R11.2, U2.6 (I/O2)
MD-: R8.1, U2.7 (I/O1)
MLED: U3.3 (P1.10), U7.1 (B), U7.2 (A)
MLED_Enable: Q2.1 (G), R5.1, U1.4 (EN), U3.13 (P0.28)
MLED_ctrl: U7.4 (Y); also elsewhere on the board
MRESET: J2.2, U3.48 (P0.24)
MROW0: D1.1 (K), D2.1 (K), D3.1 (K), D4.1 (K), D5.1 (K), D6.1 (K), D7.1 (K), D8.1 (K), D9.1 (K), D10.1 (K), D11.1 (K), D12.1 (K), D13.1 (K), D14.1 (K), U3.4 (P1.11)
MROW1: D15.1 (K), D16.1 (K), D17.1 (K), D18.1 (K), D19.1 (K), D20.1 (K), D21.1 (K), D22.1 (K), D23.1 (K), D24.1 (K), D25.1 (K), D26.1 (K), D27.1 (K), D28.1 (K), D29.1 (K), U3.6 (P1.13)
MROW2: D30.1 (K), D31.1 (K), D32.1 (K), D33.1 (K), D34.1 (K), D35.1 (K), D36.1 (K), D37.1 (K), D38.1 (K), D39.1 (K), D40.1 (K), D41.1 (K), D42.1 (K), D43.1 (K), D44.1 (K), U3.8 (P1.15)
MROW3: D45.1 (K), D46.1 (K), D47.1 (K), D48.1 (K), D49.1 (K), D50.1 (K), D51.1 (K), D52.1 (K), D53.1 (K), D54.1 (K), D55.1 (K), D56.1 (K), D57.1 (K), D58.1 (K), U3.10 (P0.29)
MROW4: D59.1 (K), D60.1 (K), D61.1 (K), D62.1 (K), D63.1 (K), D64.1 (K), D65.1 (K), D66.1 (K), D67.1 (K), D68.1 (K), D69.1 (K), D70.1 (K), D71.1 (K), U3.12 (P0.31)
MROW5: D72.1 (K), D73.1 (K), D74.1 (K), D75.1 (K), D76.1 (K), D77.1 (K), D78.1 (K), D79.1 (K), D80.1 (K), D81.1 (K), D82.1 (K), U3.14 (P0.30)
MSCL: Brd1.3 (SCL), Conn1.4, Conn2.4, Conn3.4, Conn4.4, ESD1.1 (K), R12.2, U3.22 (P0.06)
MSDA: Brd1.4 (SDA), Conn1.3, Conn2.3, Conn3.3, Conn4.3, ESD1.2 (K), R7.2, U3.20 (P0.04)
MSWDCLK: J2.6, U3.53 (SWDCLK)
MSWDIO: J2.4, U3.51 (SWDIO)
MUSB_DET: R16.1, R17.2, U3.9 (P0.03)
MVBAT: C6.1, Q1.2 (S), R9.2, TP1.1, U4.3 (V_{BAT})
MVBUS: C3.1, C5.1, J1.A4 (VBUS), J1.A9 (VBUS), J1.B4 (VBUS), J1.B9 (VBUS), Q1.1 (G), R3.1, R16.2, U2.1 (VBUS), U2.8 (VBUS), U3.32 (VBUS), U4.4 (V_{DD})
MVSYS: C1.1, C2.1, C8.1, Conn1.2, Conn2.2, Conn3.2, Conn4.2, L2.1, Q3.3 (D), U1.5 (IN), U3.30 (VDDH)
MV_WT: Q1.3 (D), Q3.2 (S), R6.2
unnamed: D1.2 (A), SW1.2
unnamed: D2.2 (A), SW2.2
unnamed: D3.2 (A), SW3.2
unnamed: D4.2 (A), SW4.2
unnamed: D5.2 (A), SW5.2
unnamed: D6.2 (A), SW6.2
unnamed: D7.2 (A), SW7.2
unnamed: D8.2 (A), SW8.2
unnamed: D9.2 (A), SW9.2
unnamed: D10.2 (A), SW10.2
unnamed: D11.2 (A), SW11.2
unnamed: D12.2 (A), SW12.2
unnamed: D13.2 (A), SW13.2
unnamed: D14.2 (A), SW14.2
unnamed: D15.2 (A), SW15.2
unnamed: D16.2 (A), SW16.2
unnamed: D17.2 (A), SW17.2
unnamed: D18.2 (A), SW18.2
unnamed: D19.2 (A), SW19.2
unnamed: D20.2 (A), SW20.2
unnamed: D21.2 (A), SW21.2
unnamed: D22.2 (A), SW22.2
unnamed: D23.2 (A), SW23.2
unnamed: D24.2 (A), SW24.2
unnamed: D25.2 (A), SW25.2
unnamed: D26.2 (A), SW26.2
unnamed: D27.2 (A), SW27.2
unnamed: D28.2 (A), SW28.2
unnamed: D29.2 (A), SW29.2
unnamed: D30.2 (A), SW30.2
unnamed: D31.2 (A), SW31.2
unnamed: D32.2 (A), SW32.2
unnamed: D33.2 (A), SW33.2
unnamed: D34.2 (A), SW34.2
unnamed: D35.2 (A), SW35.2
unnamed: D36.2 (A), SW36.2
unnamed: D37.2 (A), SW37.2
unnamed: D38.2 (A), SW38.2
unnamed: D39.2 (A), SW39.2
unnamed: D40.2 (A), SW40.2
unnamed: D41.2 (A), SW41.2
unnamed: D42.2 (A), SW42.2
unnamed: D43.2 (A), SW43.2
unnamed: D44.2 (A), SW44.2
unnamed: D45.2 (A), SW45.2
unnamed: D46.2 (A), SW46.2
unnamed: D47.2 (A), SW47.2
unnamed: D48.2 (A), SW48.2
unnamed: D49.2 (A), SW49.2
unnamed: D50.2 (A), SW50.2
unnamed: D51.2 (A), SW51.2
unnamed: D52.2 (A), SW52.2
unnamed: D53.2 (A), SW53.2
unnamed: D54.2 (A), SW54.2
unnamed: D55.2 (A), SW55.2
unnamed: D56.2 (A), SW56.2
unnamed: D57.2 (A), SW57.2
unnamed: D58.2 (A), SW58.2
unnamed: D59.2 (A), SW59.2
unnamed: D60.2 (A), SW60.2
unnamed: D61.2 (A), SW61.2
unnamed: D62.2 (A), SW62.2
unnamed: D63.2 (A), SW63.2
unnamed: D64.2 (A), SW64.2
unnamed: D65.2 (A), SW65.2
unnamed: D66.2 (A), SW66.2
unnamed: D67.2 (A), SW67.2
unnamed: D68.2 (A), SW68.2
unnamed: D69.2 (A), SW69.2
unnamed: D70.2 (A), SW70.2
unnamed: D71.2 (A), SW71.2
unnamed: D72.2 (A), SW72.2
unnamed: D73.2 (A), SW73.2
unnamed: D74.2 (A), SW74.2
unnamed: D75.2 (A), SW75.2
unnamed: D76.2 (A), SW76.2
unnamed: D77.2 (A), SW77.2
unnamed: D78.2 (A), SW78.2
unnamed: D79.2 (A), SW79.2
unnamed: D80.2 (A), SW80.2
unnamed: D81.2 (A), SW81.2
unnamed: D82.2 (A), SW82.2
unnamed: J1.A5 (CC1), R2.1
unnamed: J1.B5 (CC2), R4.1
unnamed: J1.A6 (D+), J1.B6 (D+), U2.3 (I/O2)
unnamed: J1.A7 (D-), J1.B7 (D-), U2.2 (I/O1)
unnamed: Q3.1 (G), R6.1, SPDT1.1 (A)
unnamed: L2.2, SS34.2 (A), U1.1 (SW)
unnamed: R1.2, R13.1, U1.3 (FB)
unnamed: L1.2, U3.31 (DCCH)
unnamed: R15.1, U4.5 (PROG)

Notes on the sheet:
PWR_FLAGS
USB detection
Battery
Module connectors
Battery charger
Logic shifter
Battery Sense
SWD interface
MCU
OLED
ESD protection
USB
Keyboard matrix
Holes
Boost converter
LED switch
Global switch
Battery/USB switch

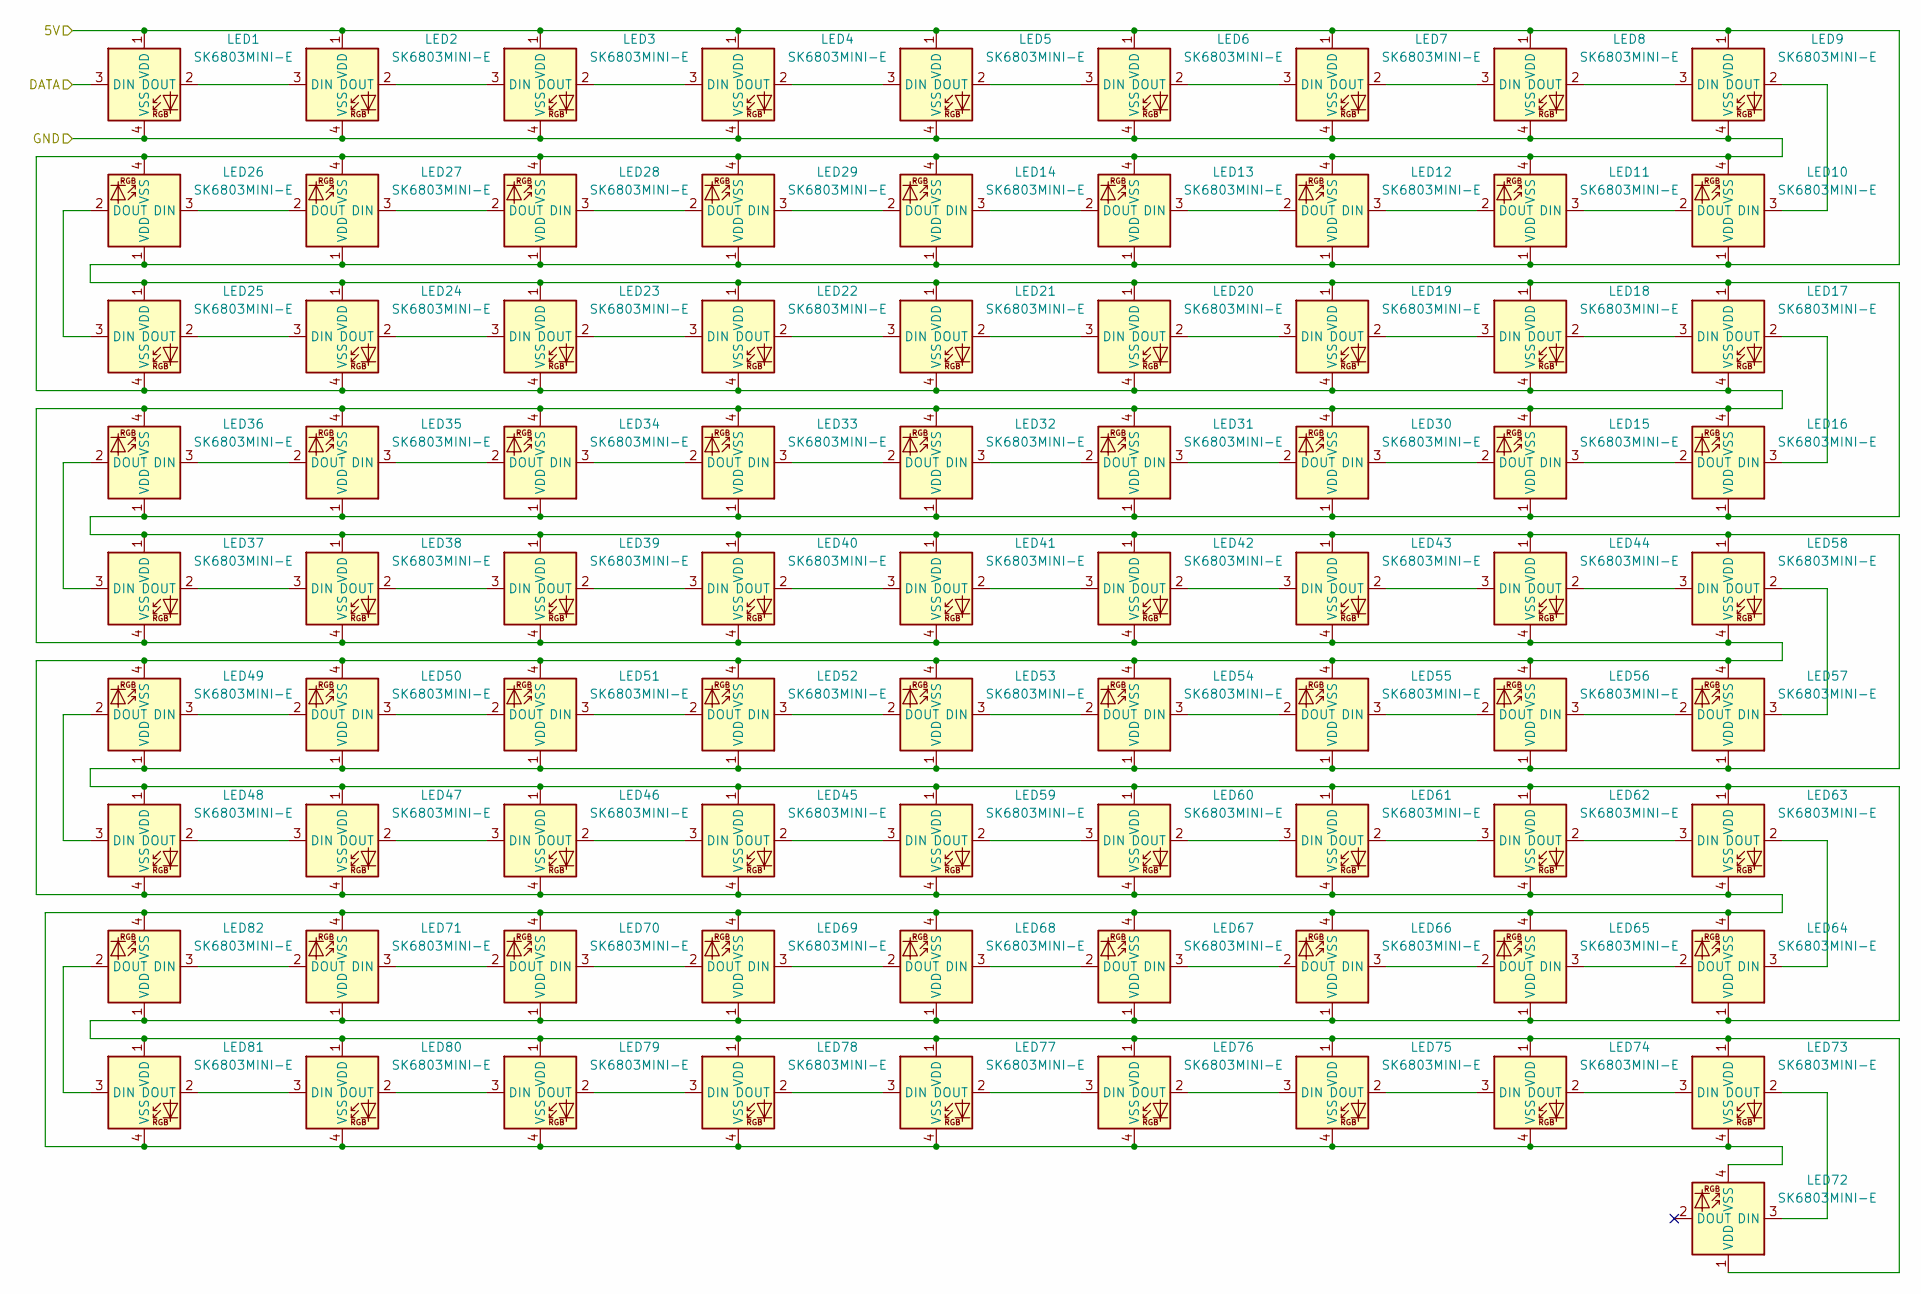
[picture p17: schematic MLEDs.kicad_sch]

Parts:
LED1, LED2, LED3, LED4, LED5, LED6, LED7, LED8, LED9, LED10, LED11, LED12, LED13, LED14, LED15, LED16, LED17, LED18, LED19, LED20, LED21, LED22, LED23, LED24, LED25, LED26, LED27, LED28, LED29, LED30, LED31, LED32, LED33, LED34, LED35, LED36, LED37, LED38, LED39, LED40, LED41, LED42, LED43, LED44, LED45, LED46, LED47, LED48, LED49, LED50, LED51, LED52, LED53, LED54, LED55, LED56, LED57, LED58, LED59, LED60, LED61, LED62, LED63, LED64, LED65, LED66, LED67, LED68, LED69, LED70, LED71, LED72, LED73, LED74, LED75, LED76, LED77, LED78, LED79, LED80, LED81, LED82: SK6803MINI-E; LED

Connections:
GND: LED1.4 (VSS), LED2.4 (VSS), LED3.4 (VSS), LED4.4 (VSS), LED5.4 (VSS), LED6.4 (VSS), LED7.4 (VSS), LED8.4 (VSS), LED9.4 (VSS), LED10.4 (VSS), LED11.4 (VSS), LED12.4 (VSS), LED13.4 (VSS), LED14.4 (VSS), LED15.4 (VSS), LED16.4 (VSS), LED17.4 (VSS), LED18.4 (VSS), LED19.4 (VSS), LED20.4 (VSS), LED21.4 (VSS), LED22.4 (VSS), LED23.4 (VSS), LED24.4 (VSS), LED25.4 (VSS), LED26.4 (VSS), LED27.4 (VSS), LED28.4 (VSS), LED29.4 (VSS), LED30.4 (VSS), LED31.4 (VSS), LED32.4 (VSS), LED33.4 (VSS), LED34.4 (VSS), LED35.4 (VSS), LED36.4 (VSS), LED37.4 (VSS), LED38.4 (VSS), LED39.4 (VSS), LED40.4 (VSS), LED41.4 (VSS), LED42.4 (VSS), LED43.4 (VSS), LED44.4 (VSS), LED45.4 (VSS), LED46.4 (VSS), LED47.4 (VSS), LED48.4 (VSS), LED49.4 (VSS), LED50.4 (VSS), LED51.4 (VSS), LED52.4 (VSS), LED53.4 (VSS), LED54.4 (VSS), LED55.4 (VSS), LED56.4 (VSS), LED57.4 (VSS), LED58.4 (VSS), LED59.4 (VSS), LED60.4 (VSS), LED61.4 (VSS), LED62.4 (VSS), LED63.4 (VSS), LED64.4 (VSS), LED65.4 (VSS), LED66.4 (VSS), LED67.4 (VSS), LED68.4 (VSS), LED69.4 (VSS), LED70.4 (VSS), LED71.4 (VSS), LED72.4 (VSS), LED73.4 (VSS), LED74.4 (VSS), LED75.4 (VSS), LED76.4 (VSS), LED77.4 (VSS), LED78.4 (VSS), LED79.4 (VSS), LED80.4 (VSS), LED81.4 (VSS), LED82.4 (VSS); also elsewhere on the board
M5V_LED: LED1.1 (VDD), LED2.1 (VDD), LED3.1 (VDD), LED4.1 (VDD), LED5.1 (VDD), LED6.1 (VDD), LED7.1 (VDD), LED8.1 (VDD), LED9.1 (VDD), LED10.1 (VDD), LED11.1 (VDD), LED12.1 (VDD), LED13.1 (VDD), LED14.1 (VDD), LED15.1 (VDD), LED16.1 (VDD), LED17.1 (VDD), LED18.1 (VDD), LED19.1 (VDD), LED20.1 (VDD), LED21.1 (VDD), LED22.1 (VDD), LED23.1 (VDD), LED24.1 (VDD), LED25.1 (VDD), LED26.1 (VDD), LED27.1 (VDD), LED28.1 (VDD), LED29.1 (VDD), LED30.1 (VDD), LED31.1 (VDD), LED32.1 (VDD), LED33.1 (VDD), LED34.1 (VDD), LED35.1 (VDD), LED36.1 (VDD), LED37.1 (VDD), LED38.1 (VDD), LED39.1 (VDD), LED40.1 (VDD), LED41.1 (VDD), LED42.1 (VDD), LED43.1 (VDD), LED44.1 (VDD), LED45.1 (VDD), LED46.1 (VDD), LED47.1 (VDD), LED48.1 (VDD), LED49.1 (VDD), LED50.1 (VDD), LED51.1 (VDD), LED52.1 (VDD), LED53.1 (VDD), LED54.1 (VDD), LED55.1 (VDD), LED56.1 (VDD), LED57.1 (VDD), LED58.1 (VDD), LED59.1 (VDD), LED60.1 (VDD), LED61.1 (VDD), LED62.1 (VDD), LED63.1 (VDD), LED64.1 (VDD), LED65.1 (VDD), LED66.1 (VDD), LED67.1 (VDD), LED68.1 (VDD), LED69.1 (VDD), LED70.1 (VDD), LED71.1 (VDD), LED72.1 (VDD), LED73.1 (VDD), LED74.1 (VDD), LED75.1 (VDD), LED76.1 (VDD), LED77.1 (VDD), LED78.1 (VDD), LED79.1 (VDD), LED80.1 (VDD), LED81.1 (VDD), LED82.1 (VDD); also elsewhere on the board
MLED_ctrl: LED1.3 (DIN); also elsewhere on the board
unnamed: LED1.2 (DOUT), LED2.3 (DIN)
unnamed: LED2.2 (DOUT), LED3.3 (DIN)
unnamed: LED3.2 (DOUT), LED4.3 (DIN)
unnamed: LED4.2 (DOUT), LED5.3 (DIN)
unnamed: LED5.2 (DOUT), LED6.3 (DIN)
unnamed: LED6.2 (DOUT), LED7.3 (DIN)
unnamed: LED7.2 (DOUT), LED8.3 (DIN)
unnamed: LED8.2 (DOUT), LED9.3 (DIN)
unnamed: LED9.2 (DOUT), LED10.3 (DIN)
unnamed: LED10.2 (DOUT), LED11.3 (DIN)
unnamed: LED11.2 (DOUT), LED12.3 (DIN)
unnamed: LED12.2 (DOUT), LED13.3 (DIN)
unnamed: LED13.2 (DOUT), LED14.3 (DIN)
unnamed: LED14.2 (DOUT), LED29.3 (DIN)
unnamed: LED15.3 (DIN), LED16.2 (DOUT)
unnamed: LED15.2 (DOUT), LED30.3 (DIN)
unnamed: LED16.3 (DIN), LED17.2 (DOUT)
unnamed: LED17.3 (DIN), LED18.2 (DOUT)
unnamed: LED18.3 (DIN), LED19.2 (DOUT)
unnamed: LED19.3 (DIN), LED20.2 (DOUT)
unnamed: LED20.3 (DIN), LED21.2 (DOUT)
unnamed: LED21.3 (DIN), LED22.2 (DOUT)
unnamed: LED22.3 (DIN), LED23.2 (DOUT)
unnamed: LED23.3 (DIN), LED24.2 (DOUT)
unnamed: LED24.3 (DIN), LED25.2 (DOUT)
unnamed: LED25.3 (DIN), LED26.2 (DOUT)
unnamed: LED26.3 (DIN), LED27.2 (DOUT)
unnamed: LED27.3 (DIN), LED28.2 (DOUT)
unnamed: LED28.3 (DIN), LED29.2 (DOUT)
unnamed: LED30.2 (DOUT), LED31.3 (DIN)
unnamed: LED31.2 (DOUT), LED32.3 (DIN)
unnamed: LED32.2 (DOUT), LED33.3 (DIN)
unnamed: LED33.2 (DOUT), LED34.3 (DIN)
unnamed: LED34.2 (DOUT), LED35.3 (DIN)
unnamed: LED35.2 (DOUT), LED36.3 (DIN)
unnamed: LED36.2 (DOUT), LED37.3 (DIN)
unnamed: LED37.2 (DOUT), LED38.3 (DIN)
unnamed: LED38.2 (DOUT), LED39.3 (DIN)
unnamed: LED39.2 (DOUT), LED40.3 (DIN)
unnamed: LED40.2 (DOUT), LED41.3 (DIN)
unnamed: LED41.2 (DOUT), LED42.3 (DIN)
unnamed: LED42.2 (DOUT), LED43.3 (DIN)
unnamed: LED43.2 (DOUT), LED44.3 (DIN)
unnamed: LED44.2 (DOUT), LED58.3 (DIN)
unnamed: LED45.3 (DIN), LED46.2 (DOUT)
unnamed: LED45.2 (DOUT), LED59.3 (DIN)
unnamed: LED46.3 (DIN), LED47.2 (DOUT)
unnamed: LED47.3 (DIN), LED48.2 (DOUT)
unnamed: LED48.3 (DIN), LED49.2 (DOUT)
unnamed: LED49.3 (DIN), LED50.2 (DOUT)
unnamed: LED50.3 (DIN), LED51.2 (DOUT)
unnamed: LED51.3 (DIN), LED52.2 (DOUT)
unnamed: LED52.3 (DIN), LED53.2 (DOUT)
unnamed: LED53.3 (DIN), LED54.2 (DOUT)
unnamed: LED54.3 (DIN), LED55.2 (DOUT)
unnamed: LED55.3 (DIN), LED56.2 (DOUT)
unnamed: LED56.3 (DIN), LED57.2 (DOUT)
unnamed: LED57.3 (DIN), LED58.2 (DOUT)
unnamed: LED59.2 (DOUT), LED60.3 (DIN)
unnamed: LED60.2 (DOUT), LED61.3 (DIN)
unnamed: LED61.2 (DOUT), LED62.3 (DIN)
unnamed: LED62.2 (DOUT), LED63.3 (DIN)
unnamed: LED63.2 (DOUT), LED64.3 (DIN)
unnamed: LED64.2 (DOUT), LED65.3 (DIN)
unnamed: LED65.2 (DOUT), LED66.3 (DIN)
unnamed: LED66.2 (DOUT), LED67.3 (DIN)
unnamed: LED67.2 (DOUT), LED68.3 (DIN)
unnamed: LED68.2 (DOUT), LED69.3 (DIN)
unnamed: LED69.2 (DOUT), LED70.3 (DIN)
unnamed: LED70.2 (DOUT), LED71.3 (DIN)
unnamed: LED71.2 (DOUT), LED82.3 (DIN)
unnamed: LED72.3 (DIN), LED73.2 (DOUT)
unnamed: LED73.3 (DIN), LED74.2 (DOUT)
unnamed: LED74.3 (DIN), LED75.2 (DOUT)
unnamed: LED75.3 (DIN), LED76.2 (DOUT)
unnamed: LED76.3 (DIN), LED77.2 (DOUT)
unnamed: LED77.3 (DIN), LED78.2 (DOUT)
unnamed: LED78.3 (DIN), LED79.2 (DOUT)
unnamed: LED79.3 (DIN), LED80.2 (DOUT)
unnamed: LED80.3 (DIN), LED81.2 (DOUT)
unnamed: LED81.3 (DIN), LED82.2 (DOUT)

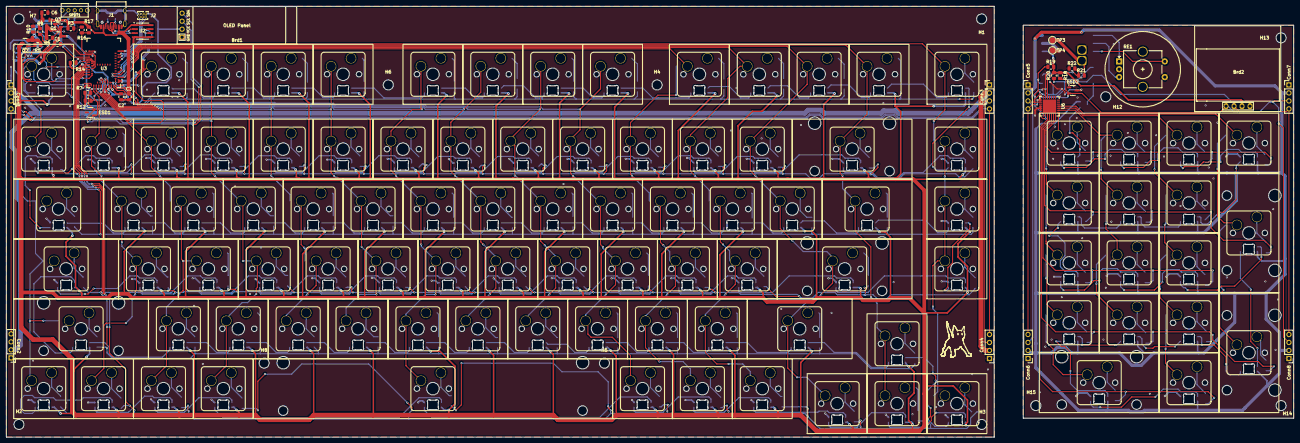
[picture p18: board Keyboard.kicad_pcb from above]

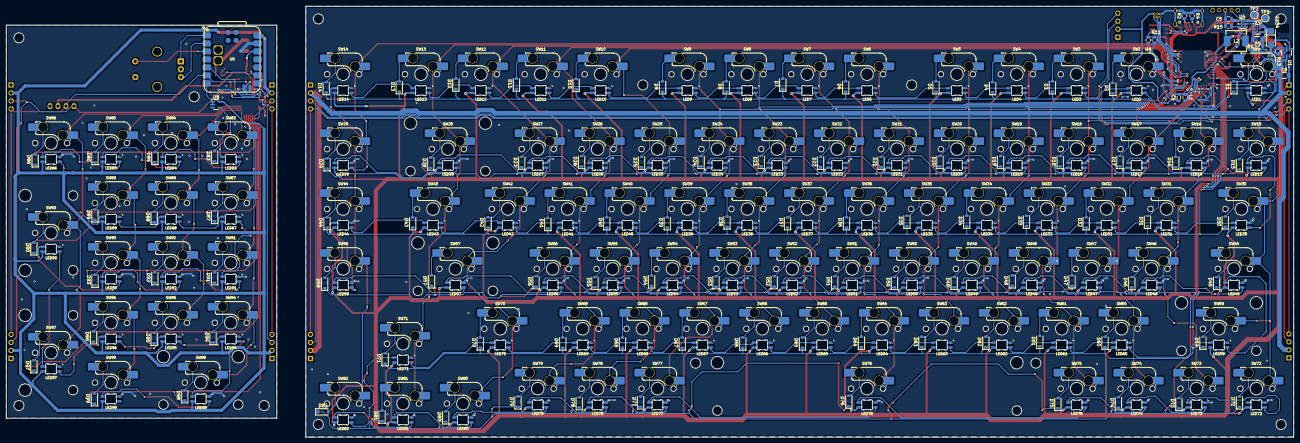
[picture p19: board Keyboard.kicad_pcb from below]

Board: 2 copper layers, 314.2 x 137.0 mm, 373 parts (318 on the bottom side), 270 nets.

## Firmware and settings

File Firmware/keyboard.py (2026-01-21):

#This is a test firmware to check if the keyboard is working properly
import board
from kmk.kmk_keyboard import KMKKeyboard
from kmk.keys import KC
from kmk.matrix import DiodeOrientation
from kmk.modules.layers import Layers

keyboard = KMKKeyboard()
keyboard.modules.append(Layers())

keyboard.diode_orientation = DiodeOrientation.COL2ROW

keyboard.row_pins = (
    board.P1_11,
    board.P1_13,
    board.P1_15,
    board.P0_29,
    board.P0_31,
    board.p0_30
)

keyboard.col_pins = (
    board.P0_27,
    board.P0_00,
    board.P1_12,
    board.P0_15,
    board.P0_16,
    board.P0_18,
    board.P0_17,
    board.P0_19,
    board.P0_21,
    board.P0_20,
    board.P0_22,    
    board.P0_23, 
    board.P1_00, 
    board.P0_24, 
    board.P0_25
)

keyboard.keymap = [
    [
        KC.ESC,  KC.F1,   KC.F2,   KC.F3,   KC.F4,   KC.F5,   KC.F6,   KC.F7,   KC.F8,   KC.F9,   KC.F10,  KC.F11,  KC.F12,  KC.NO, KC.NO,
        KC.GRV, KC.N1,   KC.N2,   KC.N3,   KC.N4,   KC.N5,   KC.N6,   KC.N7,   KC.N8,   KC.N9,   KC.N0,   KC.MINS, KC.EQL,  KC.BSPC, KC.NO,
        KC.TAB,  KC.Q,    KC.W,    KC.E,    KC.R,    KC.T,    KC.Y,    KC.U,    KC.I,    KC.O,    KC.P,    KC.LBRC, KC.RBRC, KC.BSLS, KC.HOME,
        KC.CAPS, KC.A,    KC.S,    KC.D,    KC.F,    KC.G,    KC.H,    KC.J,    KC.K,    KC.L,    KC.SCLN, KC.QUOT, KC.ENT,  KC.NO, KC.END,
        KC.LSFT, KC.Z,    KC.X,    KC.C,    KC.V,    KC.B,    KC.N,    KC.M,    KC.COMM, KC.DOT,  KC.SLSH, KC.RSFT, KC.UP,   KC.NO, KC.NO,
        KC.LCTL, KC.LGUI, KC.LALT, KC.NO,   KC.NO,   KC.SPC,  KC.NO,   KC.NO,   KC.RALT, KC.RGUI,KC.RCTL, KC.LEFT, KC.DOWN, KC.RGHT, KC.MUTE,
    ]
]

if __name__ == '__main__':
    keyboard.go()

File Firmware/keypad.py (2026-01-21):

#This is a test firmware to check if the keypad is working properly
import board
import busio
from kmk.kmk_keyboard import KMKKeyboard
from kmk.keys import KC
from kmk.scanners import DiodeOrientation
from kmk.modules.layers import Layers
from kmk.extensions.ioexpander.mcp230xx import MCP23017

keypad = KMKKeyboard()
keypad.modules.append(Layers())

i2c = busio.I2C(board.SCL, board.SDA)
mcp = MCP23017(i2c=i2c, address=0x20)

keypad.row_pins = (
    mcp.get_pin(4), 
    mcp.get_pin(3), 
    mcp.get_pin(2), 
    mcp.get_pin(1), 
    mcp.get_pin(0)
)
keypad.col_pins = (
    mcp.get_pin(5), 
    mcp.get_pin(6), 
    mcp.get_pin(8), 
    mcp.get_pin(9)
)

keypad.diode_orientation = DiodeOrientation.COLUMNS

keypad.keymap = [
    [
        KC.NLCK, KC.PSCR, KC.DOT, KC.PSLS,
        KC.P1,   KC.P2,   KC.P3,  KC.PPLS,
        KC.P4,   KC.P5,   KC.P6,  KC.PMNS,
        KC.P7,   KC.P8,   KC.P9,  KC.PENT,
        KC.PAST, KC.P0,   KC.PDOT,KC.PEQL,
    ],
]

if __name__ == '__main__':
    keypad.go()

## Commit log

2025-10-19 First schematic design
    [Keyboard.kicad_sch]
2025-10-26 Finished the schematics without LEDs
    [Keyboard.kicad_pcb, Keyboard.kicad_sch]
2025-11-09 Rearranged the key matrix and rotated the MCP
    [HS_CPG135001S30_Choc.step, Keyboard.kicad_pcb, Keyboard.kicad_sch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]
2025-11-18 Add: mounting holes
    [Keyboard.kicad_pcb, Keyboard.kicad_sch]
2025-11-23 Add: modular connectors
    [Keyboard.kicad_pcb, Keyboard.kicad_sch]
2025-11-23 One last step before finalizing the KeyPad
    [Keyboard.kicad_pcb, Keyboard.kicad_sch]
2025-11-24 Finalized the keypad
    [Keyboard.kicad_pcb, Keyboard.kicad_sch]
2025-12-10 Main board layout
    [Keyboard.kicad_pcb, Keyboard.kicad_sch, Keypad_module.kicad_sch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]
2025-12-27 Schematic checkpoint before I mess up the layout
    [Keyboard.kicad_pcb, Keyboard.kicad_sch, Keypad_module.kicad_sch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]
2025-12-27 I gave up on the hotswao modularity thing
    [Keyboard.kicad_pcb, Keyboard.kicad_sch, Keypad_module.kicad_sch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]
2025-12-31 Finished the main board's design
    [Keyboard.kicad_pcb, Keypad_module.kicad_sch, Main_board.kicad_sch]
2026-01-01 Reduced the main keyboard's profile
    [DFN-16_DHC_LIT.step, Keyboard.kicad_pcb, Keypad_module.kicad_sch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]
2026-01-01 fix issues with LTC4217
    [Keyboard.kicad_pcb, Main_board.kicad_sch]
2026-01-05 Restructure file base and update README.md
    [DFN-16_DHC_LIT.step, HS_CPG135001S30_Choc.step, Keyboard.kicad_pcb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]
2026-01-05 Added Keypad module
    [Keypad_module.kicad_sch]
2026-01-06 Add: Production files
    [Keyboard-B_Cu.gbr, Keyboard-B_Mask.gbr, Keyboard-B_Paste.gbr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]
2026-01-06 Fic: Production files
    [Keyboard-B_Cu.gbr, Keyboard-B_Mask.gbr, Keyboard-B_Paste.gbr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]
2026-01-18 Simplified design to reduce cost
    [Keypad_module.kicad_sch, Main_board.kicad_sch]
2026-01-21 Move: SMD components to top layer to reduce PCBA costs
2026-01-30 Move: Diodes to the back side
    Since I'm not getting PCBA now, I moved the diodes back to the back side of the PCB since I plan to make a keyboard plate because it keeps the dirt off and is aesthetically pleasing.
2026-02-01 Update BOM
    Changed component sourcing and added some components
2026-02-01 Update: Readme and PCB layout
2026-02-01 Production files
    Remo ed .csv from gitignore
    [MK-1000_V0.3_bom.csv, MK-1000_V0.3_designators.csv, MK-1000_V0.3_positions.csv]
2026-02-01 Update README.md
    Updated firmware section to indicate availability and added a note about the keyboard case.
2026-02-01 Add: BOM to the root directory to comply with blueprint's submission guidelines
    [bom.csv]
2026-02-10 Update: Schematic and mainboard PCB
    [Keyboard.kicad_sch, Keypad_module.kicad_sch, MLEDs.kicad_sch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]
2026-02-11 Add: 3D models
    [1825232-1.step, DFN-16_DHC_LIT.step, Magnetic Pogo Connector 5 Pin (Type 1).STEP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]
2026-02-24 Update: schematic and PCB
    Replaced the MT3608 module with a custom circuit for it.
    [DFN-16_DHC_LIT.step, IND-SMD_L6.6-W7.1-H3.0.step, Keypad_module.kicad_sch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]
2026-03-01 Update: change footprint to V1V2, update 3D models, Add rotary encoder and 128x32 OLED, Remove second 128x64 OLED
    [EC11_Rotary_Encoder_Switched.step, KeyCap_U2_V.step, KeyCap_U6.step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]
2026-03-15 Update: Changed keyswitch footprints to HS MX switches
    [HS_CPG151101S11_MX.step, KeyCap_U6.25.step, Keypad_module.kicad_sch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]
2026-03-15 Init: Keyboard Case
    Development only
    [Keyboard case (init).step, Keypad_module.kicad_sch, Main_board.kicad_sch]
2026-03-28 Update: CAD
    [Keyboard case (init).step, Keypad_case.glb.step]
2026-03-28 Update README.md
    Updated images and modified switch type in the description.
2026-03-28 Update README.md
    Updated the schematic images
2026-03-29 Add: Keyboard_case.step
    Renamed Keypad_case.glb.step => Keypad_case.step
    [Keyboard_case.step, Keypad_case.step]
2026-03-29 Update README.md
    Case image
2026-04-01 Update: Added total cost and separated gerber files.
    [MK-1000_V0.3_bom.csv, MK-1000_V0.3_designators.csv, MK-1000_V0.3_positions.csv]
2026-04-01 Add: f3d files
    And updated readme to add a section where I explain about why this project was made as per submission guidelines.
    [Keyboard_case.f3d, Keypad_case_top.glb.f3d]
2026-04-01 Update README.md
    Added battery connection wiring diagram
